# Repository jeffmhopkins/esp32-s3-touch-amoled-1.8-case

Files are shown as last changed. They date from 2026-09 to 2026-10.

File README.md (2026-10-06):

# Deep back plate — ESP32-S3-Touch-AMOLED-1.8

> **Status:** Living · **Last verified:** 2026-10-06

A 3D-printable back cover for the [Waveshare
ESP32-S3-Touch-AMOLED-1.8](https://www.waveshare.com/esp32-s3-touch-amoled-1.8.htm), the little
touchscreen that runs the kids' pet (firmware in
[JBrain2](https://github.com/jeffmhopkins/JBrain2/tree/main/firmware)).
The stock back only fits a tiny battery. This one is a deeper box that holds a real one, screws on
with the original four screw positions, and has grip ribs so small hands don't drop it.

| | |
|---|---|
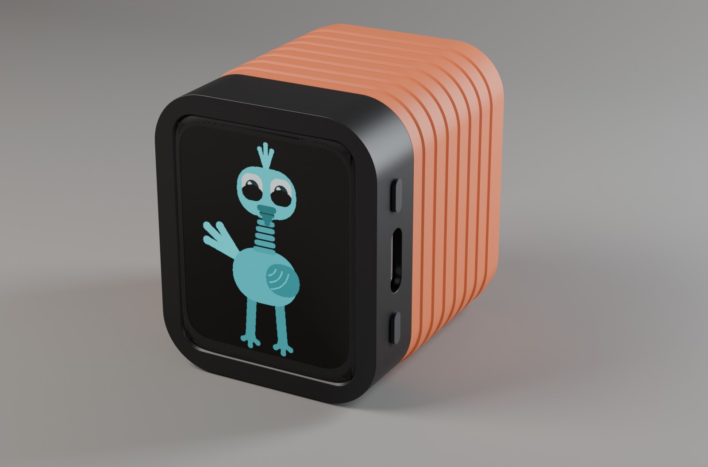
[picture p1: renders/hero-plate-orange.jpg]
The recommended back plate (103035, 1000 mAh) in orange, the pet on its screen
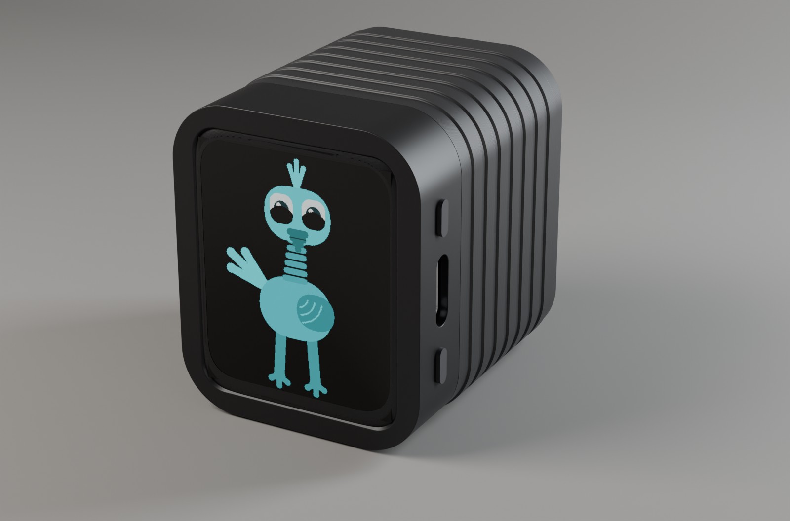
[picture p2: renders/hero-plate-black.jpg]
The same back plate in black
|  |  |

*Rendered from the model, with Waveshare's 3D model of the board and the firmware's own pet on the
glass, in orange and in black. Print it in any colour.*

## Pick a version

| | [**103035, 1000 mAh**](renders/version-103035.png) (recommended) | [802525, 400 mAh](renders/version-802525.png) | [104050, 2400 mAh](renders/version-104050.png) |
|---|---|---|---|
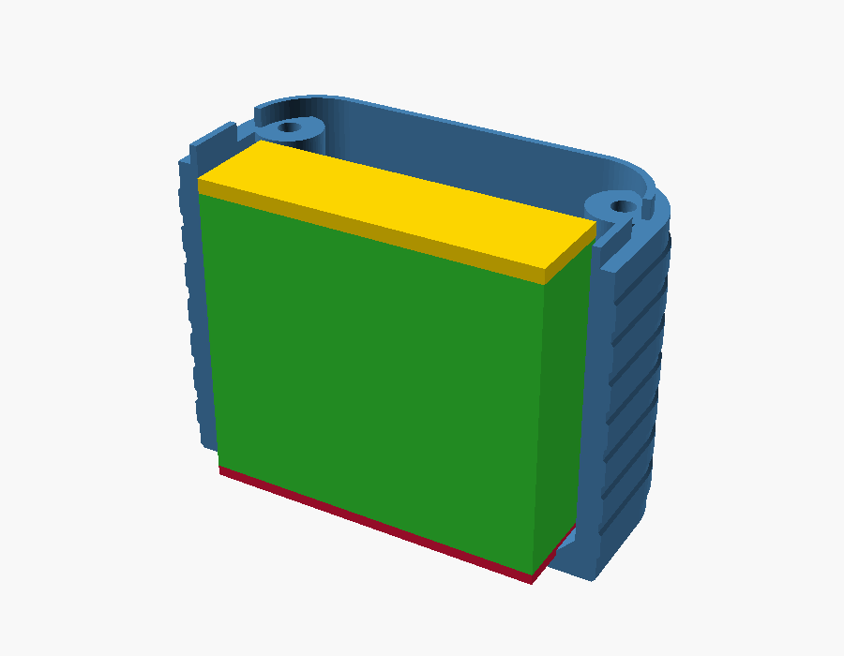
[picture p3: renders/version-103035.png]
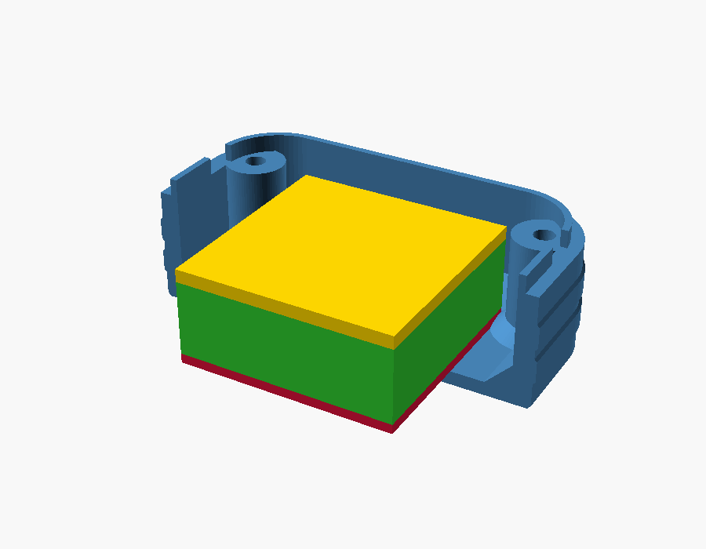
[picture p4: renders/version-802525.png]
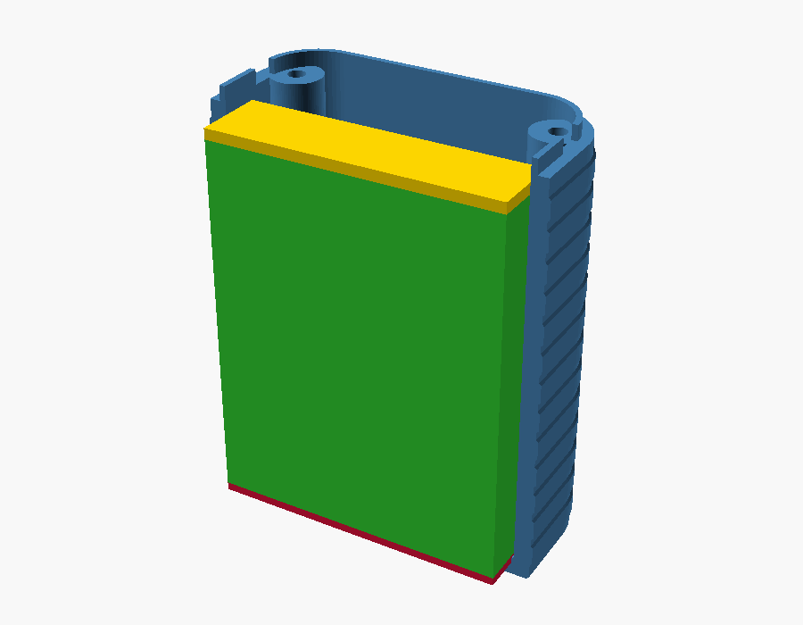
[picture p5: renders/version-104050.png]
| |  |  |  |
| Print | `back_plate_103035_1000mAh_edge.stl` | `back_plate_802525_400mAh_flat.stl` | `back_plate_104050_2400mAh_end.stl` |
| Battery sits | on its edge | flat | on its end |
| Finished unit | 37.6 × 45.2 × 44 mm | 37.6 × 45.2 × 24.7 mm | 37.6 × 45.2 × 67 mm |
| Notes | Roomy fit | Thinnest | Tight fit — measure the cell first |

Green is the battery, red the tape under it, yellow the foam on top. Optional:
`amoled18_hole_plugs.stl`, press-in caps that hide the screw openings — **not for babies, they're
a choking hazard**.

## Or: the desk stand

| | |
|---|---|
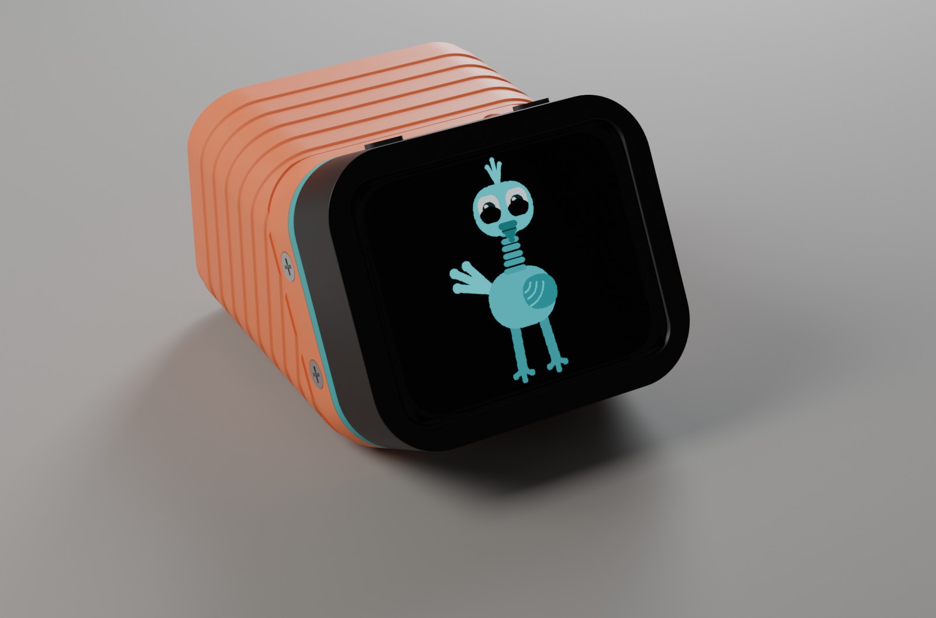
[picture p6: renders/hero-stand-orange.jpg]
The recommended desk stand (103035 box) in orange with a teal head: it lies on its side, the screen leans back 30°, USB-C and buttons along the top, a teal collar between the box and the display
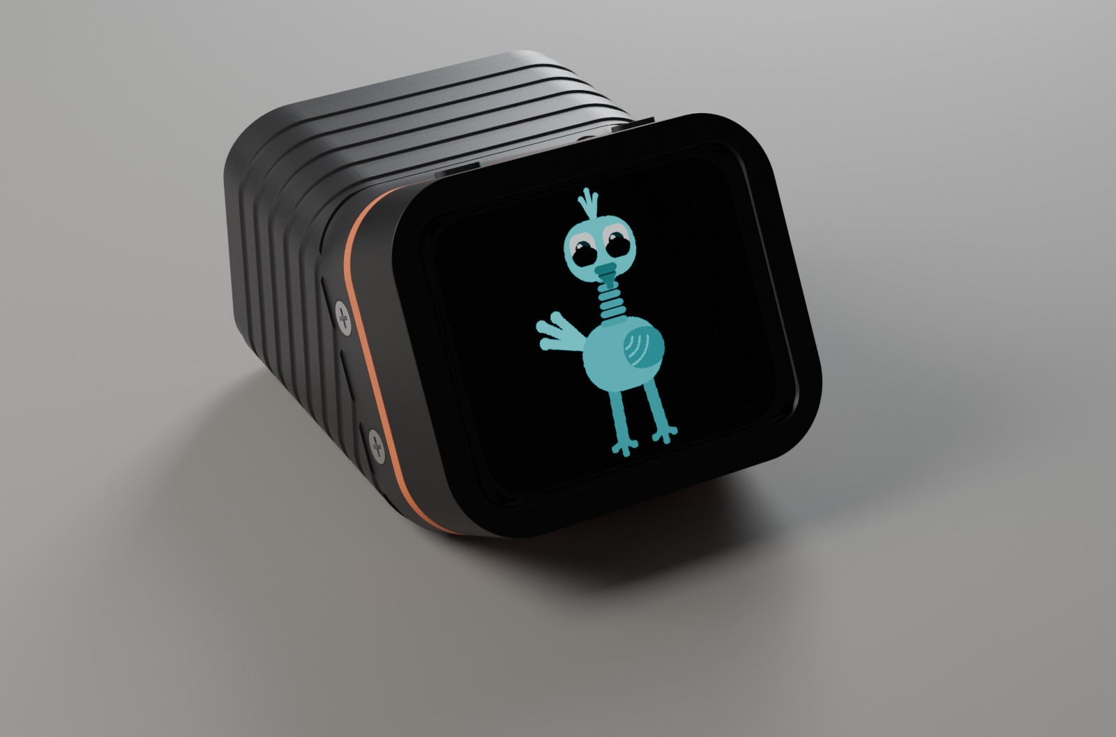
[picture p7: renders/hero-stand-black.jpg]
The same desk stand, a black box with an orange head
|  |  |

A two-part version for a desk. A **head** screws to the display in place of the stock cover,
then sinks into the angled end of a plain **battery box**, held by six flush countersunk
screws round its rim. Above the box the head widens into a 3 mm **collar**, flush with the box
and the front shell, so it shows as a band between them: print the head in a different colour
for each unit to tell them apart. The collar's underside is sloped, so it prints without
supports. The box lies on its long flat side, and the screen faces you,
landscape, leaning back 30° from upright, with the USB-C and buttons along its top edge.
The head is the same for every box, so changing battery only means printing another box.

| | [**103035, 1000 mAh**](renders/stand-section-103035.png) (recommended) | [802525, 400 mAh](renders/stand-section-802525.png) | [104050, 2400 mAh](renders/stand-section-104050.png) |
|---|---|---|---|
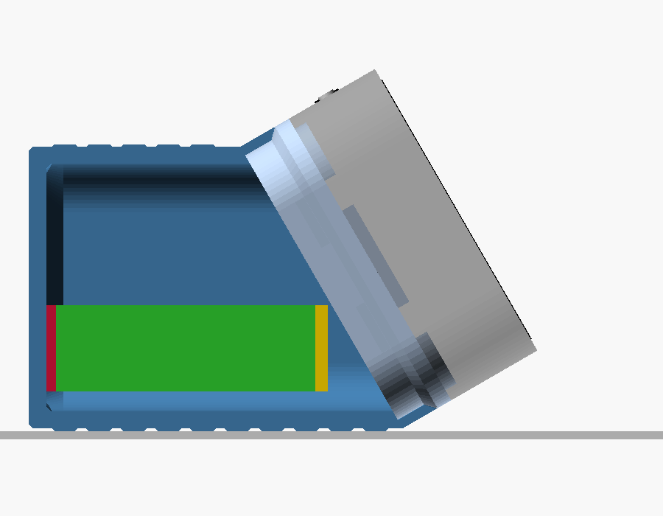
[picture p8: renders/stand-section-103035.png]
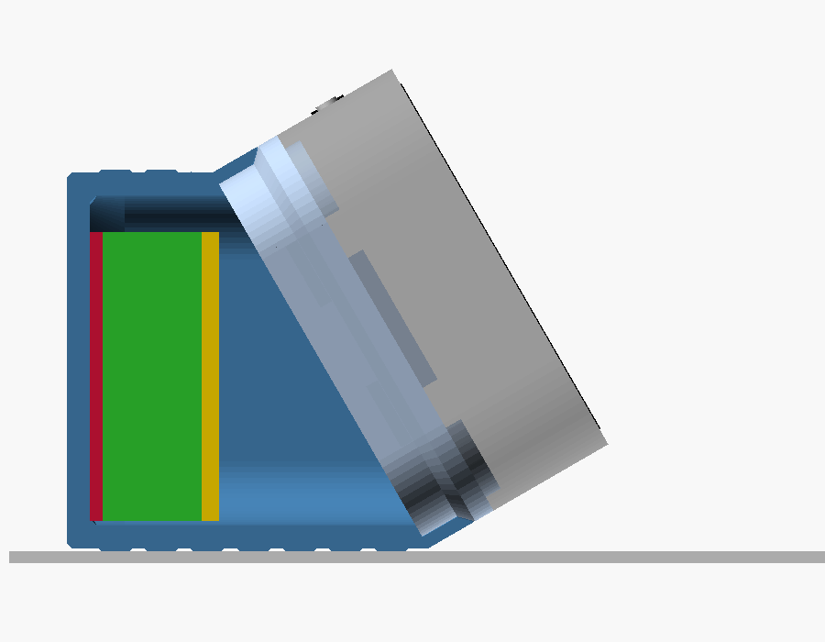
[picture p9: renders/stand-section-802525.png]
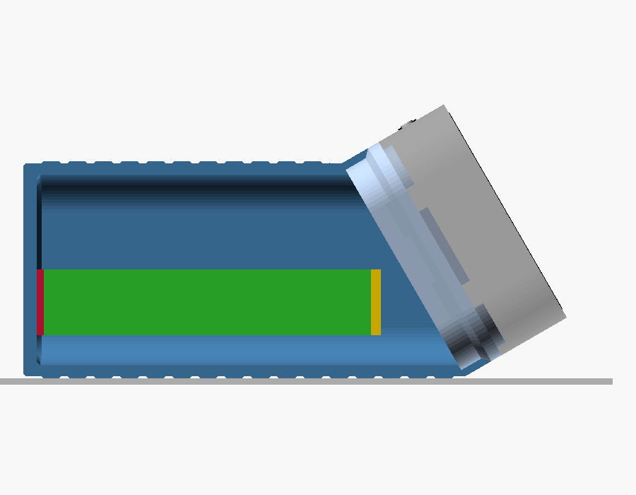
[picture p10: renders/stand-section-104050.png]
| |  |  |  |
| Print | `amoled18_stand_head.stl` + `amoled18_stand_box_103035_edge.stl` | head + `amoled18_stand_box_802525_flat.stl` | head + `amoled18_stand_box_104050_end.stl` |
| Box | 46 × 45 × 34 mm | 34 × 45 × 34 mm | 71 × 45 × 34 mm |
| With the display on | 59 × 45 × 42 mm | 47 × 45 × 42 mm | 83 × 45 × 42 mm |
| Notes | Roomy | Shortest | Tight fit — measure the cell first |

Each is cut open as it sits on the table, you on the right: battery green, tape red, foam yellow.
Sizes are front to back × left to right × height. How to print and assemble it:
[PRINTING.md](PRINTING.md#desk-stand).

If you'd rather not have the collar, `amoled18_stand_head_no_collar.stl` is the same head at
the stock cover's height. It needs boxes without the collar's 45° ramp: export them from the
box presets with `collar_h` set to 0 ([MODEL_ADJUSTMENT.md](MODEL_ADJUSTMENT.md#the-head-presets)).

## The guides

| I want to… | Read |
|---|---|
| Print it and put it together | [**PRINTING.md**](PRINTING.md) |
| Change it: another battery, a better fit, different grip | [**MODEL_ADJUSTMENT.md**](MODEL_ADJUSTMENT.md) |
| Fix something that came out wrong | [**TROUBLESHOOTING.md**](TROUBLESHOOTING.md) |
| Understand how it's built and where every number came from | [DESIGN.md](DESIGN.md) |

## Safety

These go to small children. Keep the hole plugs away from babies (glue them in or leave them
off), never squeeze a lithium pouch cell, don't install one that's puffed or damaged, check the
battery plug's polarity before connecting it, and don't leave it charging unattended.

## What's in this repo

| File | What it is |
|---|---|
| `back_plate_*.stl` | Ready-to-print plates, one per version |
| `amoled18_hole_plugs.stl` | Six press-fit plugs |
| `amoled18_stand_head.stl`, `amoled18_stand_box_*.stl` | The desk stand: one head (with its collar), a box per battery |
| `amoled18_stand_head_no_collar.stl` | The same head without the collar (for boxes made with `collar_h` 0) |
| `amoled18_back_plate.scad` | The adjustable model ([MODEL_ADJUSTMENT.md](MODEL_ADJUSTMENT.md)) |
| `amoled18_back_plate.json` | The versions and the desk stand's parts as OpenSCAD presets |
| `renders/` | Every image in these guides, and `make_renders.sh` to regenerate them |
| `photos/` | The real unit |
| `.github/workflows/release.yml` | Cuts a release with every STL attached: Actions tab → Release → Run workflow |
| `reference/` | Archived Waveshare drawings, 3D model, schematic and web pages ([reference/README.md](reference/README.md)) |
| `LICENSE` | CC BY-SA 4.0, below |

## License

The design (the model, STLs, renders, guides and photos) is licensed under
[CC BY-SA 4.0](https://creativecommons.org/licenses/by-sa/4.0/): print it, share it, sell prints,
or remix it, as long as you credit this repo and share remixes under the same license. The
files in `reference/` are Waveshare's, kept unmodified for reference, and are not covered.

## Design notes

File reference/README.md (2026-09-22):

# Reference files

> **Status:** Living · **Last verified:** 2026-09-22

Waveshare's published files for the ESP32-S3-Touch-AMOLED-1.8, kept here so the back plate's
defaults can be checked without depending on their site staying up. Every file here is an
unmodified copy of Waveshare's original; the table says where each one came from.

| File | What it is | Used for |
|---|---|---|
| `waveshare-dimensions.webp` | Official dimension drawing ([source](https://docs.waveshare.com/ESP32-S3-Touch-AMOLED-1.8)) | Case outline 37.6 × 45.2 × 15.0 mm, corner radius, back label window 27.6 × 27.6 R1.8 |
| `waveshare-3d-model.zip` | STEP model of the board and display, without the case shells ([source](https://files.waveshare.com/wiki/ESP32-S3-Touch-AMOLED-1.8/ESP32-S3-Touch-AMOLED-1.8-3D.zip)) | PCB 33.0 × 40.6 mm and its four mounting holes, 24 × 36 mm apart |
| `waveshare-schematic.pdf` | Board schematic ([source](https://files.waveshare.com/wiki/ESP32-S3-Touch-AMOLED-1.8/ESP32-S3-Touch-AMOLED-1.8.pdf)) | Battery connector and charging circuit |
| `pages/` | Saved copies of the web pages the numbers came from (see below) | Keeping the sources if Waveshare's site changes |
| `measure.py` | Re-derives the numbers above from these files | Checking or updating the `.scad` defaults |

## Saved web pages

Saved 2026-09-22. Open them in a browser; they read fine offline, though images other than
the dimension drawing aren't included.

| File | Page | How it was saved |
|---|---|---|
| `pages/docs-main.html` | [Waveshare docs: overview](https://docs.waveshare.com/ESP32-S3-Touch-AMOLED-1.8), with the dimension drawing and the MX1.25 battery connector | Direct download |
| `pages/docs-resources.html` | [Waveshare docs: resources](https://docs.waveshare.com/ESP32-S3-Touch-AMOLED-1.8/Resources-And-Documents), the download links above | Direct download |
| `pages/wiki.html` | [Waveshare wiki](https://www.waveshare.com/wiki/ESP32-S3-Touch-AMOLED-1.8): "recommended battery specification is 3.85\*24\*28 400mAh" | Wayback Machine snapshot from 2026-07-23 (the live site blocks scripted downloads) |
| `pages/product.html` | [Product page](https://www.waveshare.com/esp32-s3-touch-amoled-1.8.htm): "to fit inside the case, a battery size of 3.85 × 24 × 28 mm is recommended" | Wayback Machine snapshot from 2026-09-14 |

## Using the files

The STEP file opens in any CAD program (FreeCAD, Fusion 360, Onshape) — handy for checking
clearances between the battery pocket and the parts on the back of the board.

`measure.py` output, for comparison:

```
PCB: 33.01 x 40.62 x 1.20 mm
  hole centre: (-12.05, -18.05) mm from board centre
  hole centre: (-12.09, +18.10) mm from board centre
  hole centre: (+12.06, -18.05) mm from board centre
  hole centre: (+12.01, +18.00) mm from board centre
Case corner radius: 8.8 mm (fit error 0.23 px²)
```

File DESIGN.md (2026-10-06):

# Design notes

> **Status:** Living · **Last verified:** 2026-10-06

How the plate is built, why, and where every number came from. You don't need this to print or
adjust it. Back to the [README](README.md).

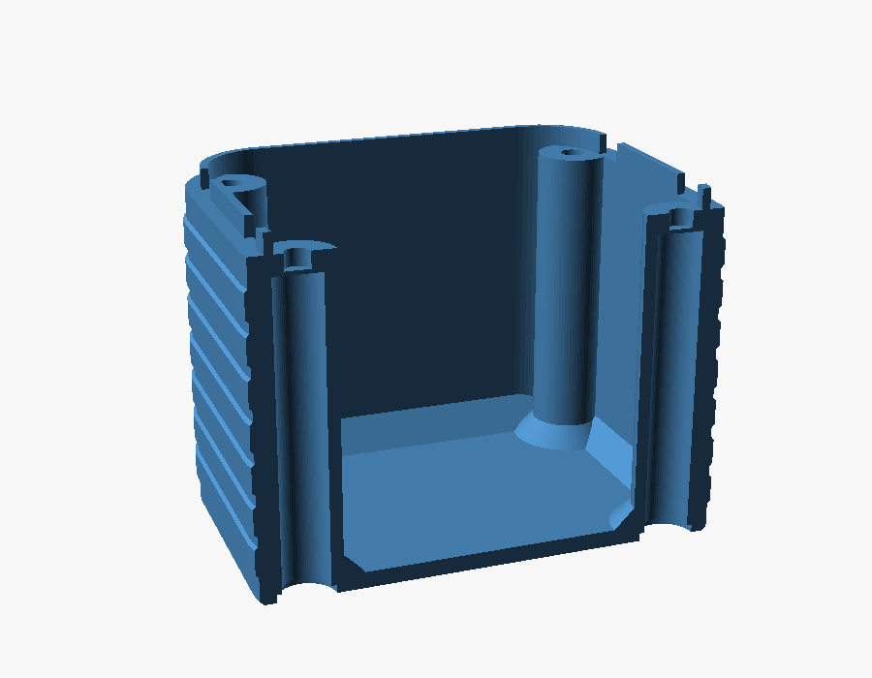
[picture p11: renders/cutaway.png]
Cut through two screw towers


## Battery cavity

The plate is a box with straight walls. The whole inside is open apart from four screw towers,
and its depth follows the battery. The cell sits on tape with foam on top, and the cavity is
deliberately not shaped to the cell: gaps are packed with foam. All ports, buttons and the mic
are in the front shell, so the plate has no other openings.

- **Orientation.** The screws pass through 24 mm apart across the case, so a wide cell can't lie
  flat past them. On its **edge** a cell is only its thickness wide there; on its **end** its
  length becomes the plate's depth, so any length fits.
- **Wire room.** A pouch cell's wires leave one end. `lead_end` (2 mm) keeps that free; the
  default still has 1.85 mm spare at each end beyond it. A 40 mm cell such as an 852540 doesn't
  fit flat or on its edge once its wires have room.
- **Clearances.** The console warns `TIGHT` when anything comes within 0.5 mm of the cell and
  refuses to export under 0.2 mm, because real cells run up to half a millimetre over.
- **Bracing.** A 45° chamfer where the walls meet the floor (`wall_chamfer`, 3 mm) and a 45°
  flare where each tower meets it (`tower_flare`, 2 mm). Both shrink near the cell to stay
  0.5 mm off its bottom edge, so they never lift it.
- **The board's `BAT` connector** stands 3.5 mm off the back of the board, on one long side about
  halfway along. The flat 802525 sits under it, so that version leaves 2 mm extra above the cell.
- **The rim** is the top of the wall itself (0.8 mm), so it stands squarely on the wall with
  nothing overhanging. Its opening is the cavity. It has a 4 mm slot 8.5 mm either side of the
  middle of each short side (`mic_slots`), behind the U-shaped speaker/mic notch in the front
  shell's edge, so the rim doesn't close that notch off. There are four so it clears whichever
  way round the part goes on; the shell hides the ones it doesn't need.

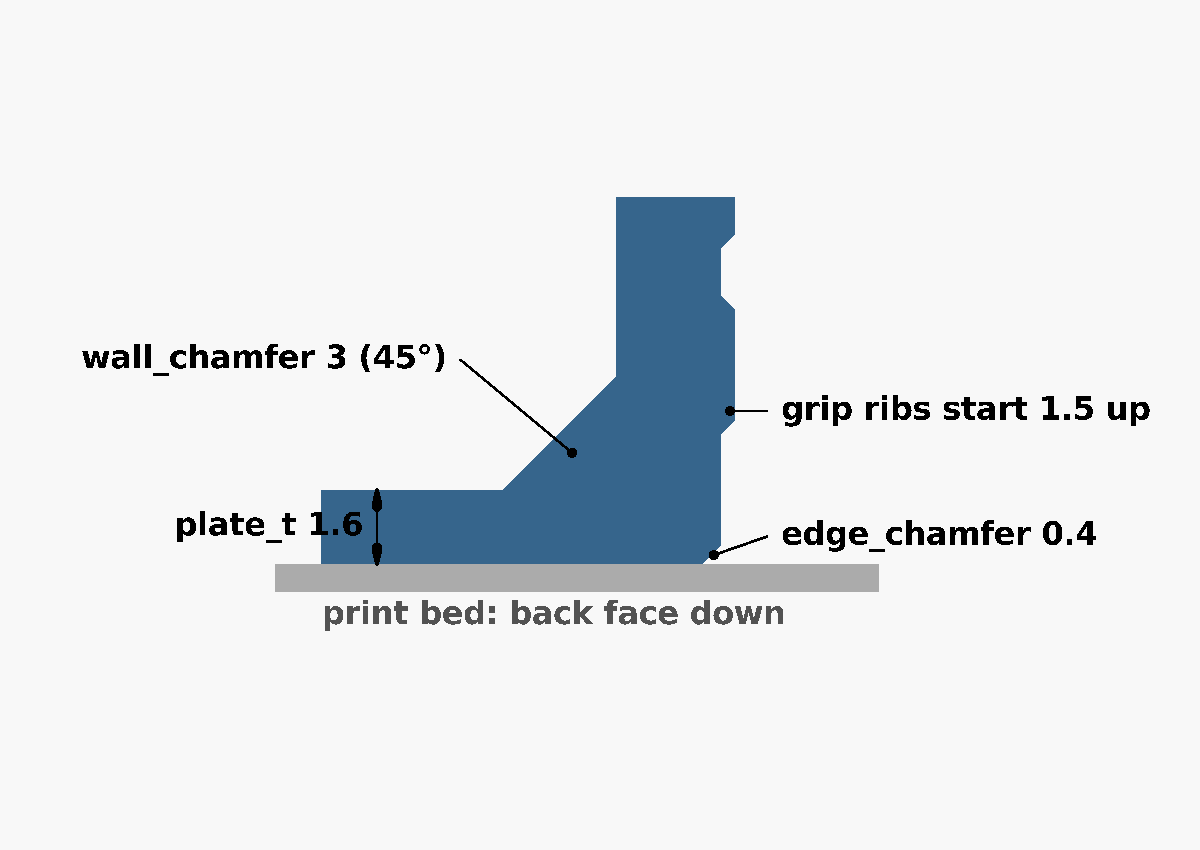
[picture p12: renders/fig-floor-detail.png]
Bottom of the wall: floor, chamfer, bed edge


## Screws

The screws thread into brass hex standoffs soldered to the **board**, not the case. They stand up
from the board and end exactly level with the front shell's edge. On the stock cover a post
around each screw presses its standoff, so tightening clamps the board. This plate does the same
with four hollow towers:

- The bore (Ø4.6) takes the screw head and hex key up to the **seat**, 2 mm of plastic at the top
  (`head_seat`). The screw only passes through the seat into the standoff, so short screws work
  at any plate height.
- The tower top is flat and full width (Ø7) and stops at the seam, level with the front shell's
  edge, where it presses squarely on the standoff (`tower_drop` = 2, the rim's height). The rim
  then goes its full 2 mm into the shell. If the top ever needs to stand clear of parts near a
  standoff, `nut_pad_h` raises a Ø4.5 pad around it instead.
- A thin skin (`bridge_skin`, 0.4 mm — two layers) closes each bore so the printer can bridge it;
  it's cleared at assembly.

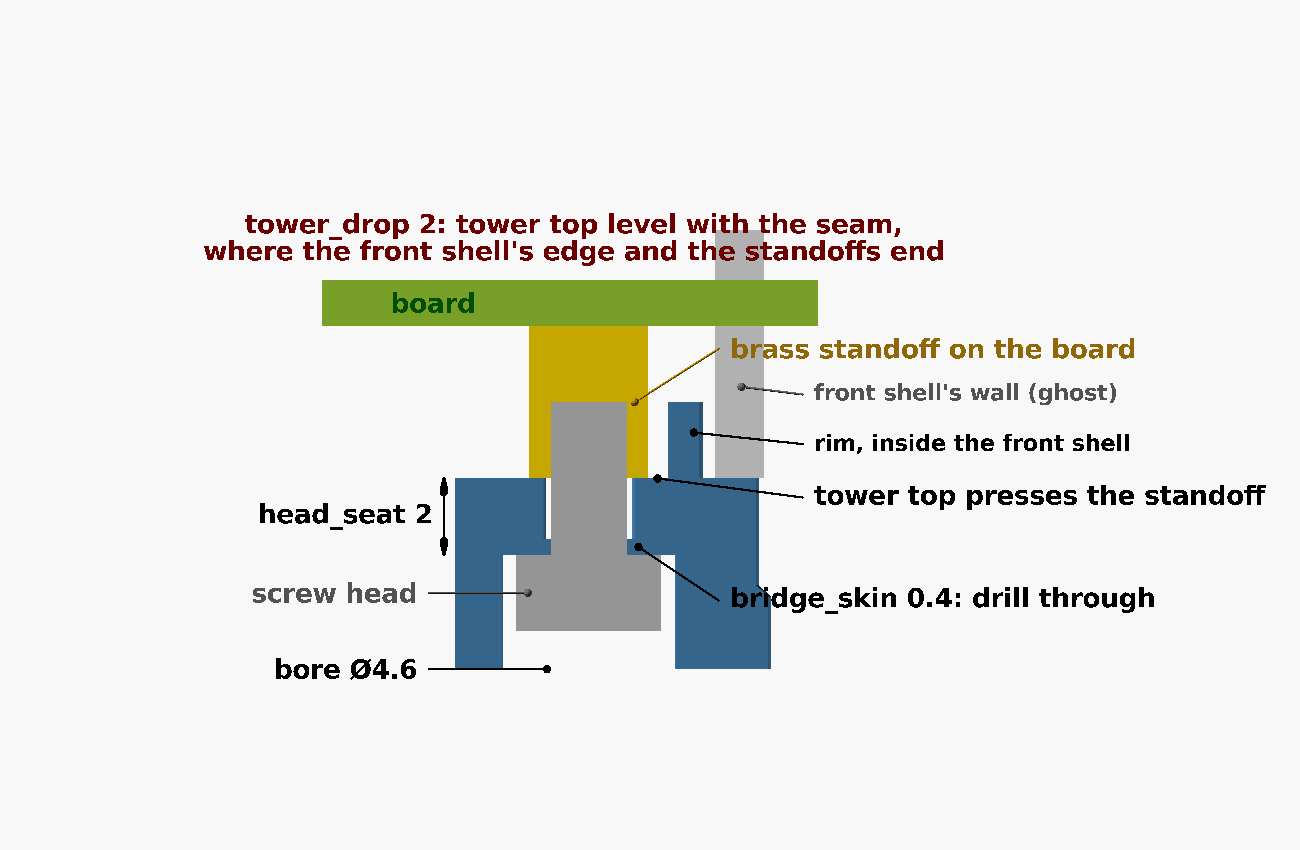
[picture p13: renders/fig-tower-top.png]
Top of a screw tower, with the screw, the board's standoff and the board


| The standoffs end level with the front shell's edge | The four standoffs on the board |
|---|---|
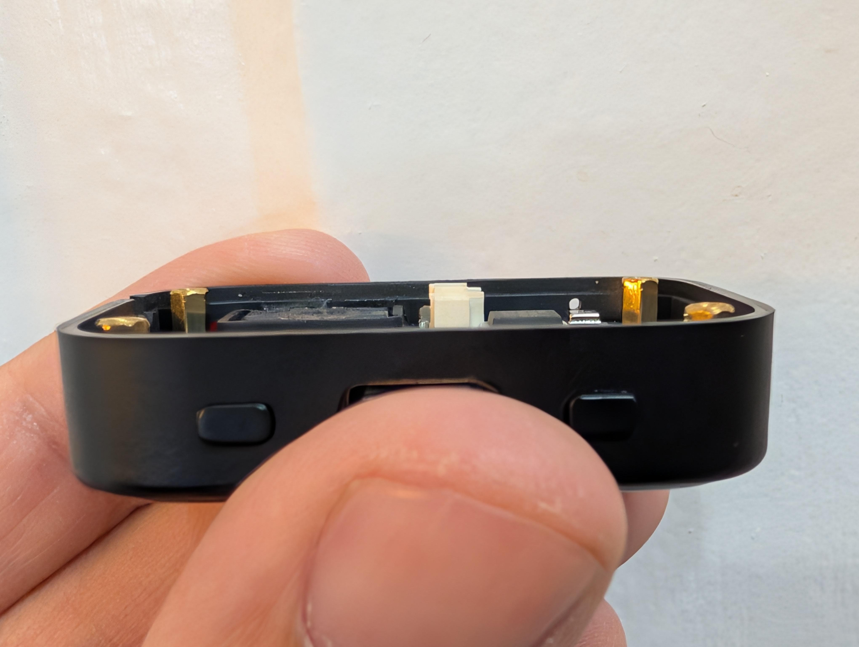
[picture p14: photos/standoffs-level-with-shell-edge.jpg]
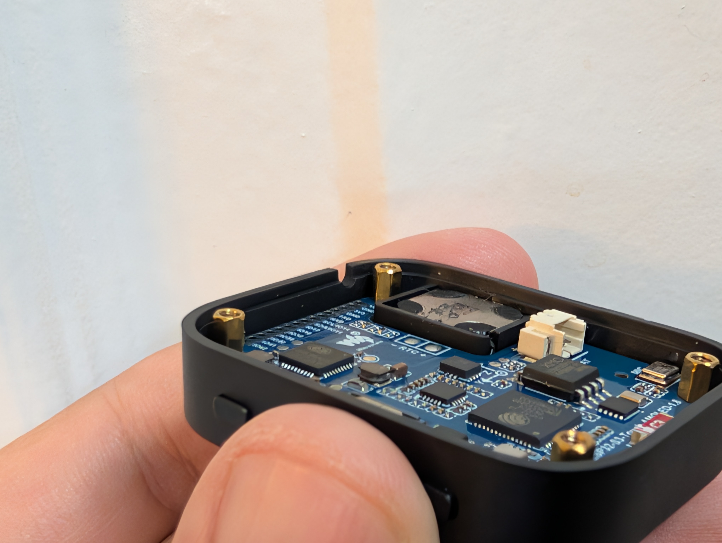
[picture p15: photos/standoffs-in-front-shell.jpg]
|  |  |

**Screw length.** The screw passes the 2 mm seat and goes into the standoff; M2 × 4 gives 2 mm of
thread in it, M2 × 5 gives 3. Push a stock screw through the stock cover to see how far it goes
into its standoff, and don't go much past that: the standoff's thread may not run its full
length. On the desk stand's head the seat is 1.4 mm (the head is too thin for a socket head
under a 2 mm seat), so its M2 × 4 go 2.6 mm in.

## Hole plugs

A shallow recess (Ø5.6 × 0.8) at each tower opening, and plugs with a thin cap and a ribbed
shank: six ribs that crush slightly going in, for a press fit with no glue. A small gap around
each cap lets a knife tip pry it out. They're a choking hazard for babies.

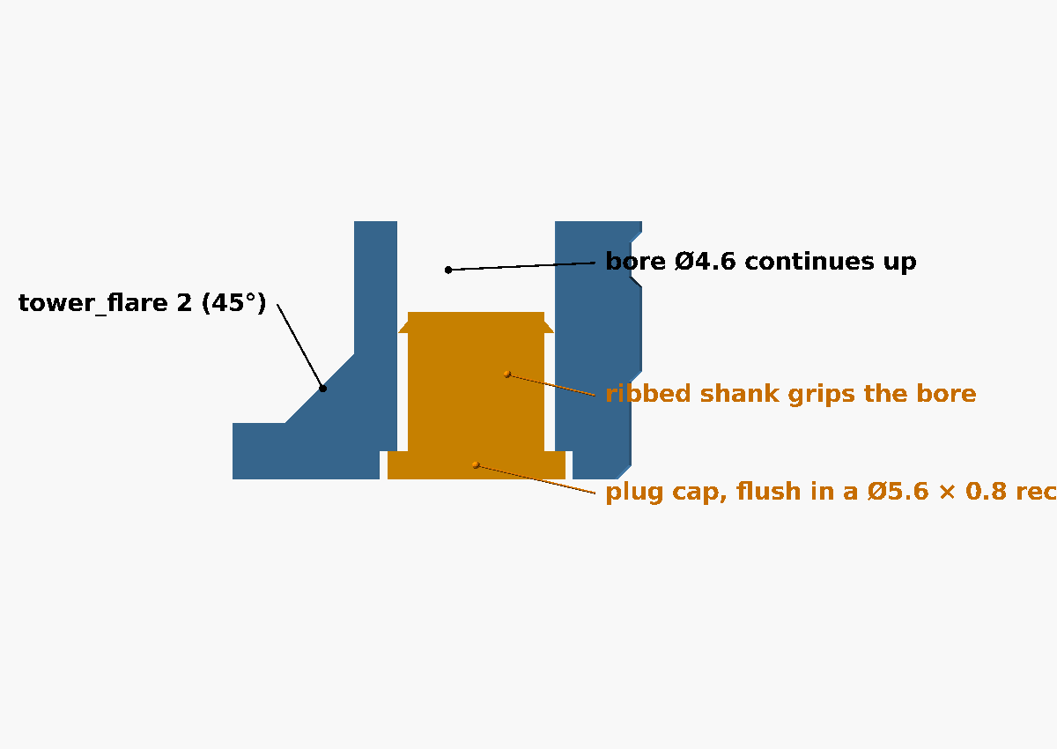
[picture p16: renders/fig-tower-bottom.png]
A fitted plug in section


## Grip

Horizontal ribs right round the outside, corners included: bands 3 mm tall, 0.3 mm proud by
default (`grip_depth`, 0–0.5), with 45° slopes top and bottom so they print without supports.
They stop 1.5 mm short of the bed edge and the seam.

## The tall 104050 version

A 104050 (10 × 40 × 50 mm, sold as 2400 mAh; expect about 2000) standing on its 10 × 40 face,
wires at the top, about 67 mm tall overall. Its 40 mm width sits in a 40.7 mm opening — 0.35 mm
per end, hence "measure first"; set `lip_wall` to 0.6 for 41.1 mm if it's over. The common
listing ships a JST PH 2.0 plug that needs swapping for 1.25 mm. The screws are the same M2 × 4;
the hex driver needs a 60 mm shaft.

## The desk stand

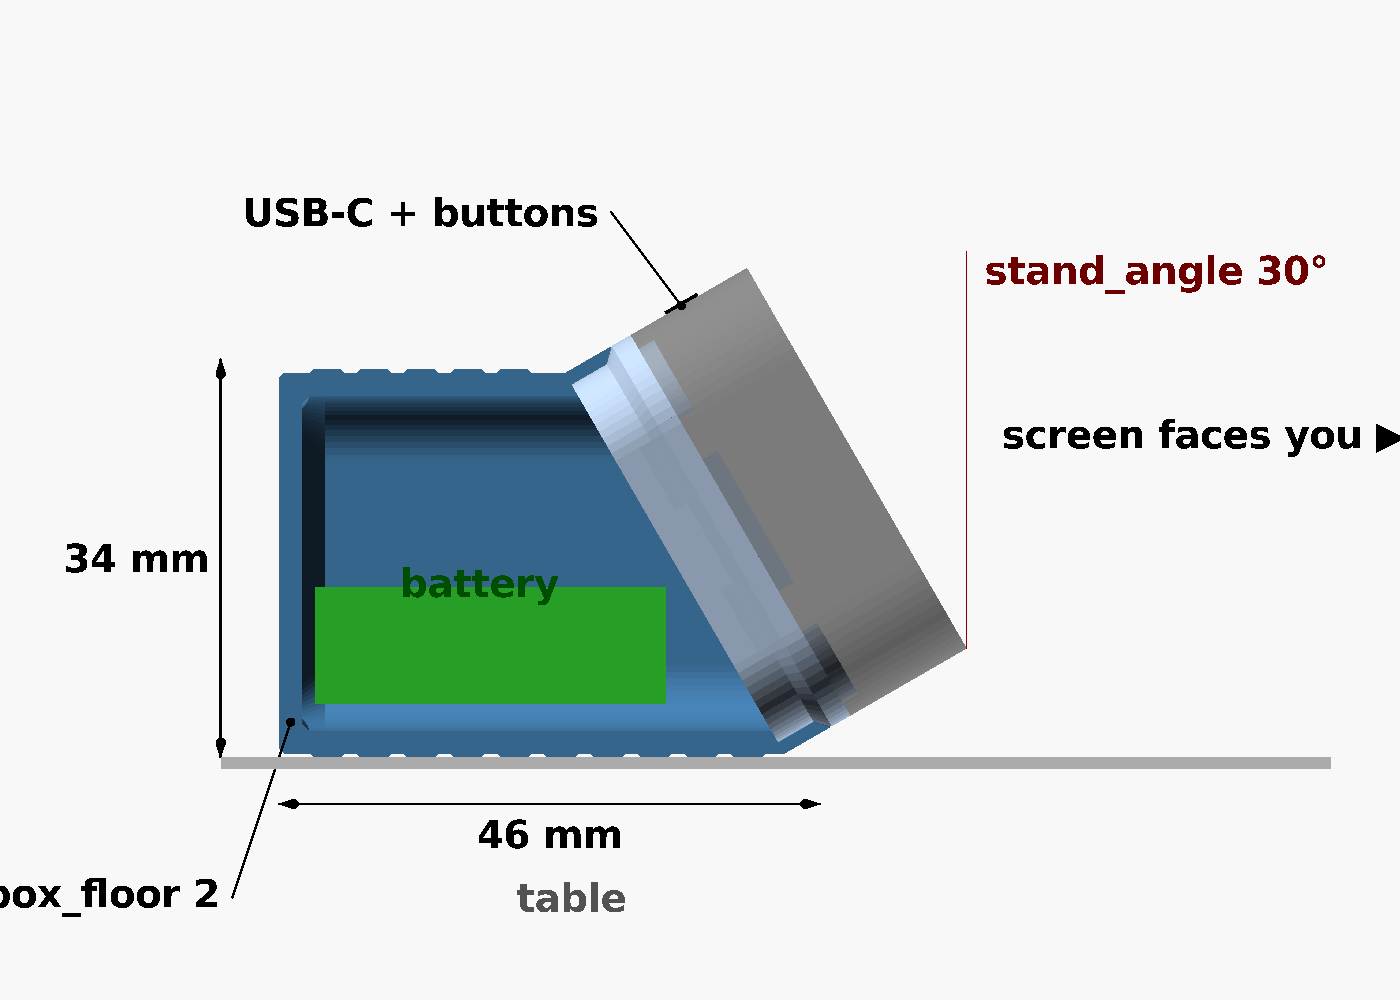
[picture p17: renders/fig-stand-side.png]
The desk stand from the side


Two parts, so the box stays a plain box and the part that meets the display stays the stock
cover's shape. The head that ships adds a collar and a few fit changes to what's described
below (the model's defaults, which the boxes are built from); see
[The collar head](#the-collar-head) at the end of this section.

- **The head** is the plate at stock depth (5.5 mm) with no battery room: same rim, same four
  towers, so it fits the front shell exactly as the stock cover does. It is smaller than the case
  by the box's rim wall, with corners that follow the case's: the box's opening is the case outline
  offset in by the band's width, so the band is the same 1.1 mm all the way round, corners
  included. (Tighter head corners pinched the band to 0.3 mm at each corner, too thin to
  print.) That leaves 0.83 mm of wall outside each screw bore in the head, with the head
  presets' slightly tighter bore (`head_clear` 0.4). It adds a solid block for each lock screw
  inside its short ends (left and right in
  use), and a slot through the floor just in front of the board's `BAT` socket, whose mouth faces
  the slot (from Waveshare's 3D model). The socket is on the side away from the USB-C, which fixes
  which way round the head goes. Its back edge has no chamfer, so all of it bears on the ledge,
  and its tower flares don't change with the battery, so one head fits every box.
- **The box** is a straight-walled prism, printed standing on its floor. Its open end is cut at
  `stand_angle`, and the head sinks into it: its back rests on a ledge `stand_ledge` wide inside,
  and round it the box's wall carries on `pocket_wall` thick to the seam, where the front shell
  sits on it. The outside of that band is the case outline, so box and front shell are flush;
  the head's rim stands above the seam into the front shell as usual. Below the ledge the box is
  open under the head, so the head's back is its lid. Where its walls meet the floor there's a
  45° chamfer, kept under the tape beside the cell as on the plate.
- **How it sits.** In use the box lies on its long flat wall, with the cut end facing you, so the
  screen leans back `stand_angle` from upright. The display goes in with its USB-C edge (the
  head's +x, where the two buttons are too) to the box's short wall, which puts it along the top.
  Nothing of the box stands past the seam, so the USB-C plug and the buttons are clear. Lying on
  a side 45 mm wide and as long as the box, it's low and steady.
- **Box size.** The cell lies on that long flat wall, as far along it as its corners allow 0.5 mm
  from the rounded corners. The box is then made just long enough that the head clears the top of
  the cell (in the print frame) plus tape, foam, wires and `extra_clearance`, but its short wall
  is never shorter than `stand_front_min`. The box is modelled in its print frame; `part = stand`
  shows it lying as it's used (`stand_pose()` in the `.scad`).
- **Printing.** Standing on its floor, the box's walls are vertical and its cut end slopes at
  `stand_angle`, so it prints with no supports; the band's walls lean at that angle too, the
  same as the front shell's. The band is 1.1 mm at the sides and about 1.3 mm along the long and
  short walls.
- **Screws.** Four M2 × 4 hold the display to the head, as on the plate, though here the seat is
  1.4 mm and the holes 2.1 mm deep so a socket head fits inside the thin head. Six M2 × 8
  countersunk lock screws hold the head in the box: two on each side, `lock_spread` (14 mm) apart,
  and one each in the top and bottom, diagonally opposite so they clear the battery slot and the
  head still fits either way round. Each goes through the band round the box's angled end into a
  lock block in the head, cutting its own thread about 5.6 mm deep. An M2 countersunk head needs
  only a 0.8 mm 90° seat, so the heads sit flush in the 1.1 mm band. The holes are 1.45 mm up from
  the ledge, which keeps each seat under the seam with the front shell; its lower edge dips into
  the solid wall below the ledge.
- **Pads and notches.** The band alone is 1.1 mm, thin for a screw to clamp on, so at each screw
  the box has a pad on the band's inside, 6 mm wide, reaching `lock_pad` (1.0 mm) in — no further
  than the ledge, so it stands on solid wall — and the head has a matching notch in its edge. The
  wall under each screw head is 2.25 mm. The notch's roof, and the pad's top, slope at 45°, so the
  head's rim above each notch is held up by solid plastic instead of printing as a bridge. The
  pads also key the head into the box before it's screwed.

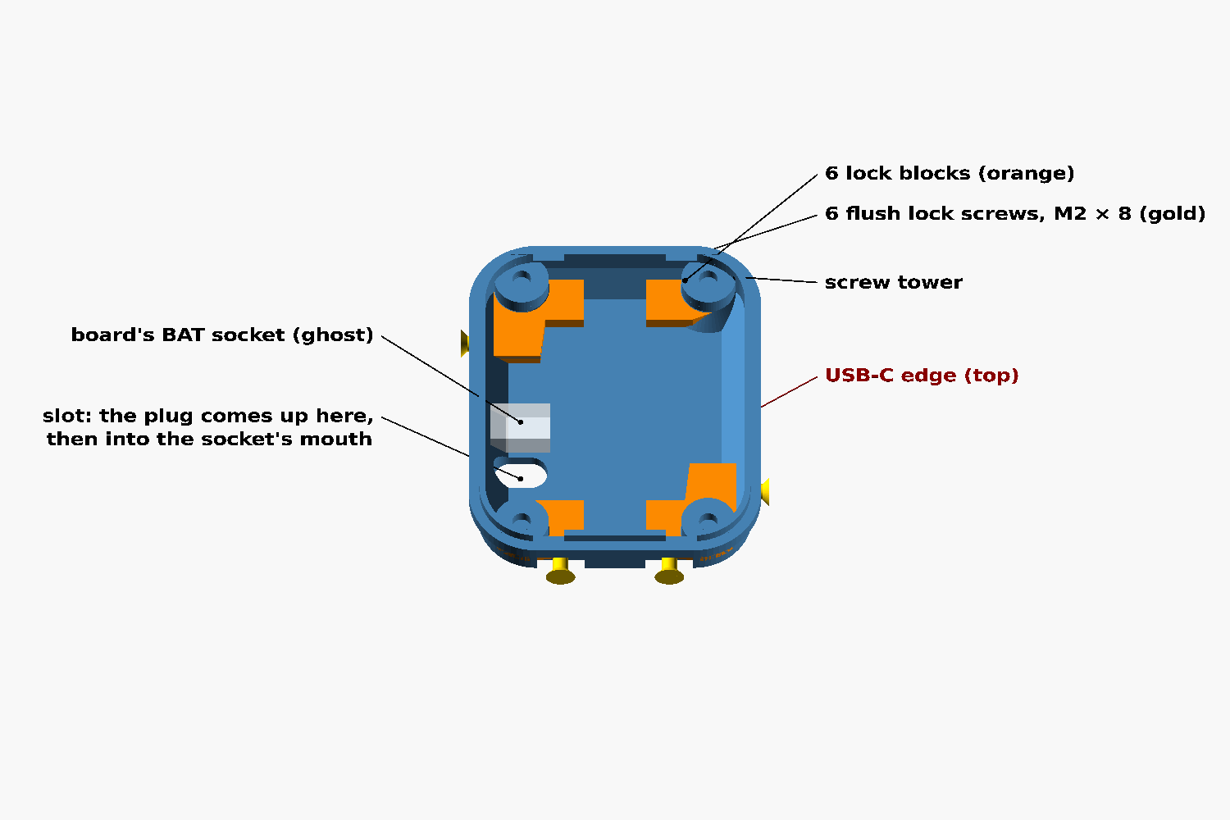
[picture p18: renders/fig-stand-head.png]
The head from inside, with the BAT socket ghosted


### The collar head

The head that ships (`amoled18_stand_head.stl`, preset **Desk stand: head (fits every box)**)
is the head above with these changes; `amoled18_stand_head_no_collar.stl` (preset **Desk
stand: head, no collar**) has all of them but the collar. Each one came from fitting a stand
on a second unit, where the stock head was loose in the box and the front shell sat above it.

- **A 3 mm collar** (`collar_h`). Above the box's band the head widens to the case outline,
  so the box, collar and front shell are flush. The part in the box (`pocket_h`) is unchanged.
  The collar's underside slopes up at 45° from the head's side (`collar_chamfer`), so it prints
  without a sagging overhang, and the box's band rises in a matching 45° ramp that the
  collar nests on, 0.1 mm clear. The boxes therefore carry `collar_h` too: a box made with it
  has the ramp. The collar head also fits a box without the ramp, leaving a small V-groove
  between them; the no-collar head needs a box without the ramp.
- **Tower tops 0.5 mm below the seam** (`tower_drop` = `lip_h` + 0.5), so standoffs that reach
  past the shell's edge can't hold it up. The screw seat stays 2 mm thanks to the collar, and
  the screws become M2 × 5.
- **Lock blocks stay in the box** (they stop at `pocket_h`), 3 mm below the seam, and join
  their nearest tower (`lock_block_join`) so there's no narrow V between them.
- **A 1.5 mm rim** (`lip_h`; `stock_clear` drops with it so the part in the box stays 3.5 mm).
- **0.05 mm gaps** to the box and inside the shell (`pocket_clear`, `lip_slop`), with the
  lock-pad notches 0.1 mm deeper (`lock_pad`, `stand_ledge` 1.1) to match.

## Where the numbers come from

Sources: Waveshare's [dimension drawing](https://docs.waveshare.com/ESP32-S3-Touch-AMOLED-1.8) and
[3D
model](https://files.waveshare.com/wiki/ESP32-S3-Touch-AMOLED-1.8/ESP32-S3-Touch-AMOLED-1.8-3D.zip)
([resources page](https://docs.waveshare.com/ESP32-S3-Touch-AMOLED-1.8/Resources-And-Documents)),
and the photos in `photos/`. Copies are kept in [`reference/`](reference/README.md), with
`reference/measure.py` to re-derive them. The 3D model has the board and display but not the case.

| Default | Value | Source | Confidence |
|---|---|---|---|
| `plate_x` × `plate_y` | 37.6 × 45.2 | Case outline, dimension drawing | High (official) |
| `screw_dx`, `screw_dy` | 12.0, 18.0 (24 × 36 apart) | PCB mounting holes in the 3D model; drawing and photos agree within ~0.7 mm | High |
| `plate_r` | 8.7 | Circle fitted to the drawing's corners | Good, ±0.5 |
| `lip_outer_x` × `lip_outer_y`, `lip_outer_r` | 35.0 × 42.6, 7.4 | Outline minus a ~1.3 mm front-shell wall, from the photos (the board is 33.0 × 40.6) | Estimate: measure |
| `lip_h` | 2.0 | Not visible in any source | Guess: measure |
| `stock_clear` | 3.9 | Stock cover shows 3.5 mm in the side view; derived with the rim height | Estimate |
| `tower_drop` | 2.0 (= `lip_h`) | The board's standoffs end level with the front shell's edge ([photos](#screws)); 0 left a 2 mm gap at the seam on the first print | Measured |
| `lip_wall` | 0.8 | Chosen: the rim's inside is the cavity; 0.8 leaves a 40.7 mm opening | Design choice |
| `screw_size` | M2 | Heads ~3.8 mm across in the drawing (stock ones are Phillips) | Likely |
| Tower bore | Ø4.6 | ISO 4762 M2 head (Ø3.8) + `head_clear` 0.6 + `hole_slop` 0.2 (Ø4.4 in the desk-stand heads, `head_clear` 0.4) | Standard |

For reference: the stock unit is 15.0 mm thick; Waveshare's largest recommended cell for the
stock case is 3.85 × 24 × 28 mm; the stock back label window is 27.6 × 27.6 mm, R1.8.

The desk-stand head presets (`amoled18_stand_head.stl` and the no-collar head) go on from these
defaults: a 1.5 mm rim and tower tops 0.5 mm below the seam, from fitting a second unit whose
shell sat proud of the box on the defaults ([The collar head](#the-collar-head)).

## Regenerating the images

Every image in these guides is rendered from the model: `renders/make_renders.sh` rebuilds them
all (OpenSCAD 2021+; on a headless machine it uses `xvfb-run`). The figure sources are in
`renders/src/`; the labelled ones draw their dimension lines and text in OpenSCAD itself
(`renders/src/annot.scad`), so a change to the model only needs a re-run.

The photoreal shots on the README, `renders/hero-<plate|stand>-<orange|black>.jpg`, come from
`renders/photoreal/make_photoreal.sh` instead: Blender (Cycles, as the `bpy` module) renders
the printed parts exported from the model, Waveshare's STEP of the board and panel (the copy in
`reference/`, checksummed), and a pet frame drawn by the JBrain2 firmware's `face.c` (saved in
`renders/photoreal/screens/`; set `FIRMWARE` to a firmware checkout to redraw it). The STEP has
no case, so the black front shell in those shots is drawn from the case outline and the
[photos](#screws): the board hangs on standoffs that end at the seam (taken as 4 mm), which puts
the glass just under the shell's face. It takes about 25 minutes on four cores and needs `python3.11`; re-run it only
when a change shows from outside.

## Photos of the real unit

| Stock cover, inside | Assembled back | Board in the front shell |
|---|---|---|
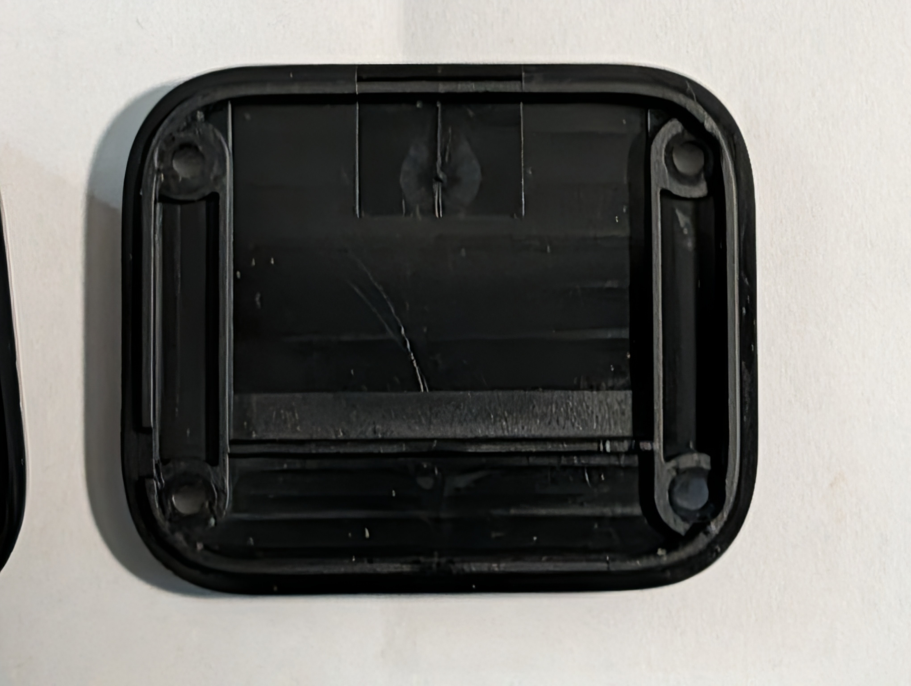
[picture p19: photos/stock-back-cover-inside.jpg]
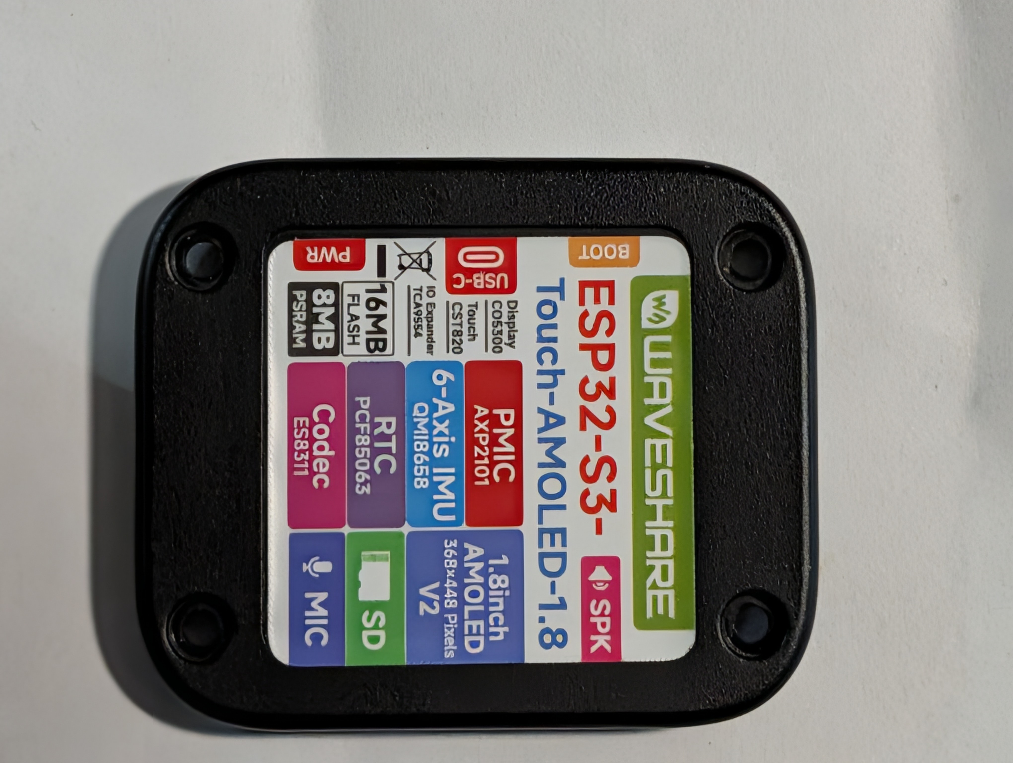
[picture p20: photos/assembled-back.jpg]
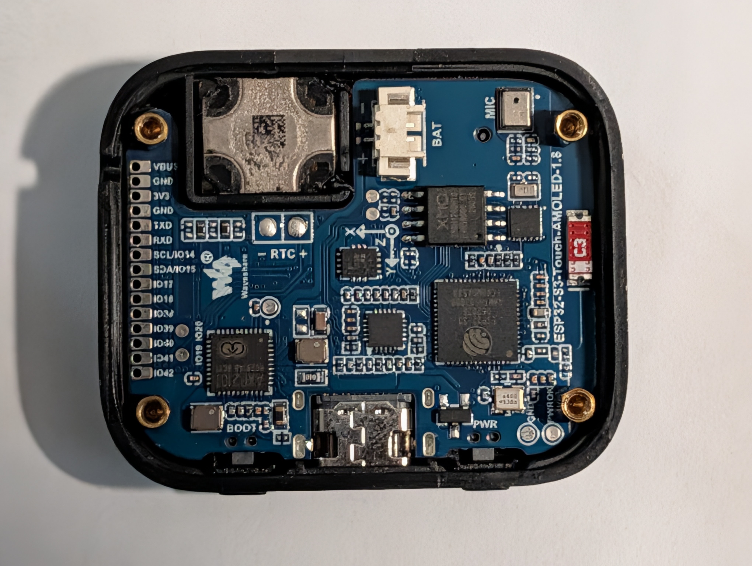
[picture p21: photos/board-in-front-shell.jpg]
|  |  |  |

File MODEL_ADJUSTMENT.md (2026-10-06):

# Adjusting the model

> **Status:** Living · **Last verified:** 2026-10-06

How to change the plate: another battery, a better fit to the case, a different grip. You never
edit code — every number is a labelled field in a form (the one exception is noted under the desk
stand). Back to the [README](README.md).

## Opening it (first time)

1. Install [OpenSCAD](https://openscad.org/downloads.html) (free, Windows/Mac/Linux).
2. Download `amoled18_back_plate.scad` **and** `amoled18_back_plate.json` into the same folder
   (on GitHub: click the file, then the download icon). The `.json` holds the ready-made versions.
3. Open the `.scad`. Turn on the form: **Window → Customizer** (on some versions untick **View →
   Hide customizer**). Press **F5** to see the part; drag to spin, scroll to zoom.
4. **Start from a version**: the drop-down at the top of the Customizer has all three, and
   the desk stand's head and boxes. Then
   change fields — the groups are numbered, and each field has a plain-English label.
5. **Read the console** at the bottom (**Window → Console** if hidden) after each **F5**:
   - `All checks passed.` — good to go.
   - `TIGHT: only … mm spare` — it fits, but with under 0.5 mm to spare. Measure your real cell.
   - `CELL DOES NOT FIT` — OpenSCAD will refuse to export until you fix it.
   It also prints the cavity size, the room around the cell, the total height and how far the hex
   key has to reach.
6. **Export**: **F6** (full render, can take a minute), then **F7** to save an `.stl`.
7. **Save your numbers**: click **+** on the preset bar and name them, or they're gone when you
   close the file.

## Quick reference

| You want to… | Change | Group |
|---|---|---|
| Use a different battery | `battery_t`, `battery_w`, `battery_l` | 1. Battery |
| Stand it up, lay it flat, stand it on end | `battery_orientation` | 1. Battery |
| Different tape or foam | `tape_t`, `foam_t` | 1. Battery |
| More room for the wires | `lead_end`, `lead_space` | 1. Battery |
| Match the case's outline | `plate_x`, `plate_y`, `plate_r` | 2. Plate outline |
| Rim fit in the front shell | `lip_outer_x`, `lip_outer_y`, `lip_h`, `lip_slop`, `lip_wall` | 3. Rim |
| Screw positions | `screw_dx`, `screw_dy` | 4. Screws |
| Tower height (how hard it presses the board) | `tower_drop` | 4. Screws |
| Holes too tight or loose on your printer | `hole_slop` | 4. Screws |
| Plug fit, or no plug recesses | `plug_interference`, `plug_recess` | 4c. Hole plugs |
| Grip ribs | `grip_depth`, `grip_style` | 5b. Grip |
| Export plugs instead of the plate | `part` | 6. Output |
| Desk stand: screen angle, box size | `desk_stand`, `stand_angle`, `stand_front_min`, `box_floor` | 7. Desk stand |
| Desk stand: how the head fits the box, lock screws, collar | `pocket_wall`, `pocket_clear`, `stand_ledge`, `lock_spread`, `lock_top_bottom`, `lock_pad`, `collar_h` | 7. Desk stand |
| See the battery in the preview | `show_battery` | 6. Output |

The sections below show what each of these is on the part.

## Battery

A cell's size code reads thickness, width, length: **103035** is 10 × 30 × 35 mm. Enter the
**real** size if you can measure it, including the little circuit board folded over at the wire
end — cheap cells often run half a millimetre over their listing.

`battery_orientation` sets how it sits:

| **edge** — on its long edge | **flat** — on its face | **end** — upright on its end |
|---|---|---|
|  |  |  |
| For cells up to about 37 mm long | For small square cells | Any length: the plate grows taller |

Why not just lay a long cell flat? The screws pass through 24 mm apart across the case, so a
wide cell would sit on them. Standing it up makes it only as wide as it is thick.

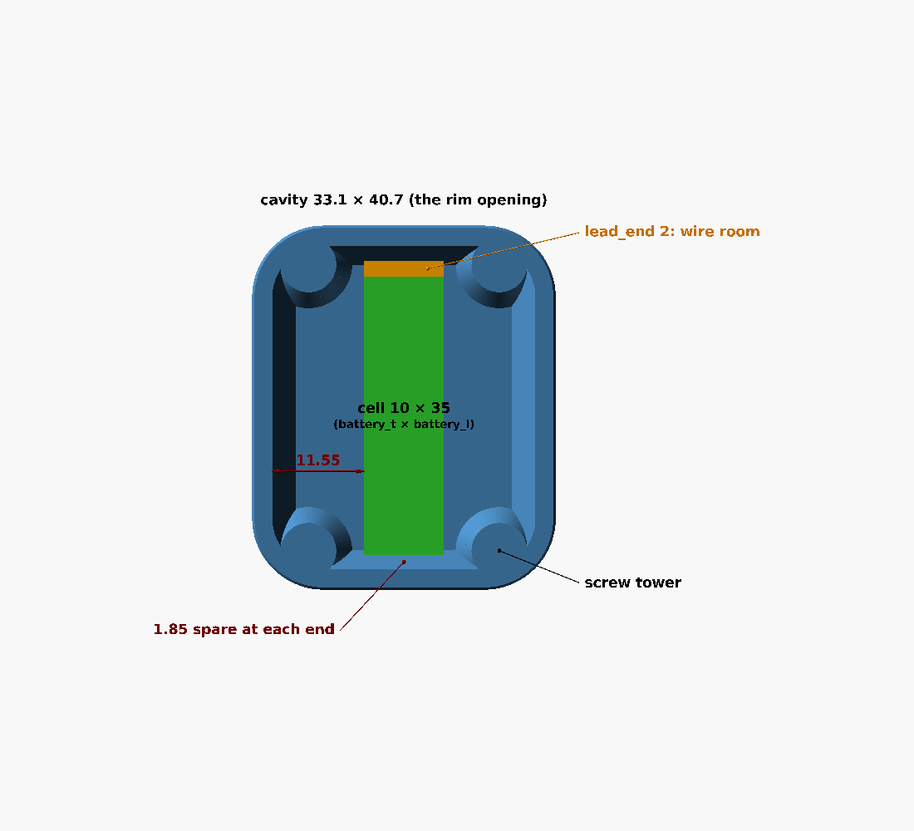
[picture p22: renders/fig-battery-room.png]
Top view of the default: the cell, its wire room and the clearances


| Field | What it does |
|---|---|
| `tape_t` | Thickness of the VHB tape under the cell (1 mm tape measures about 1.1) |
| `foam_t` | Foam on top of the cell |
| `lead_end` | Room kept free past the wire end of a flat or edge cell (orange above) |
| `lead_space` | Room above the cell for wires and plug — used for a cell on its end, whose wires come out the top |
| `extra_clearance` | A little air so nothing is squeezed |

The plate's depth follows from all of these automatically.

## Outline and screw positions

These come from Waveshare's own drawings and should already be right.

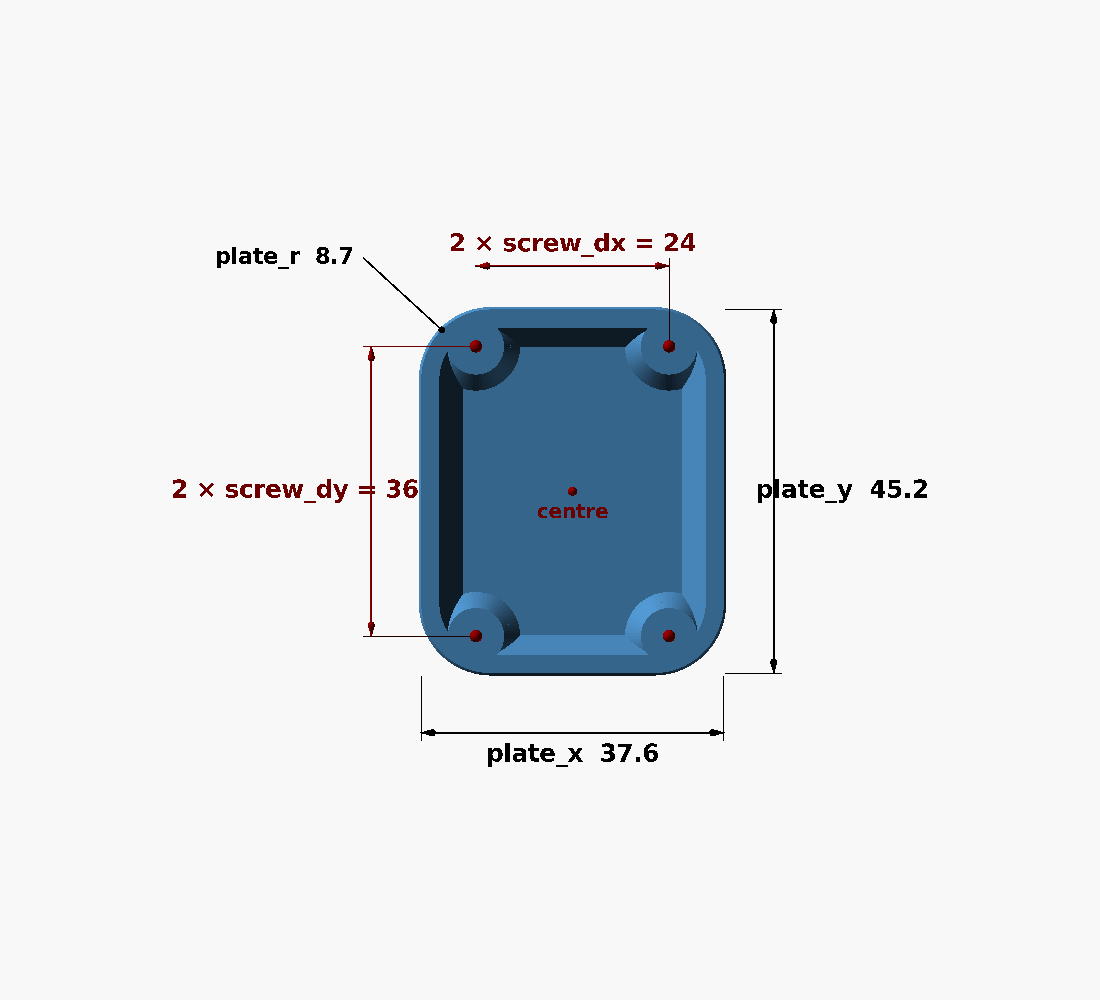
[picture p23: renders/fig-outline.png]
Outline and screw spacing


| Field | What it is | How to measure it on the stock cover |
|---|---|---|
| `plate_x`, `plate_y` | Outside width and length | Straight across |
| `plate_r` | Corner radius | Roughly how round the corners are |
| `screw_dx`, `screw_dy` | Centre to screw-hole centre, across and along | Hole to hole, then halve |

## Rim

The rim is the band on top of the wall that slides into the front shell. Its size is an
estimate from photos, so it's the thing most worth checking against the stock cover.

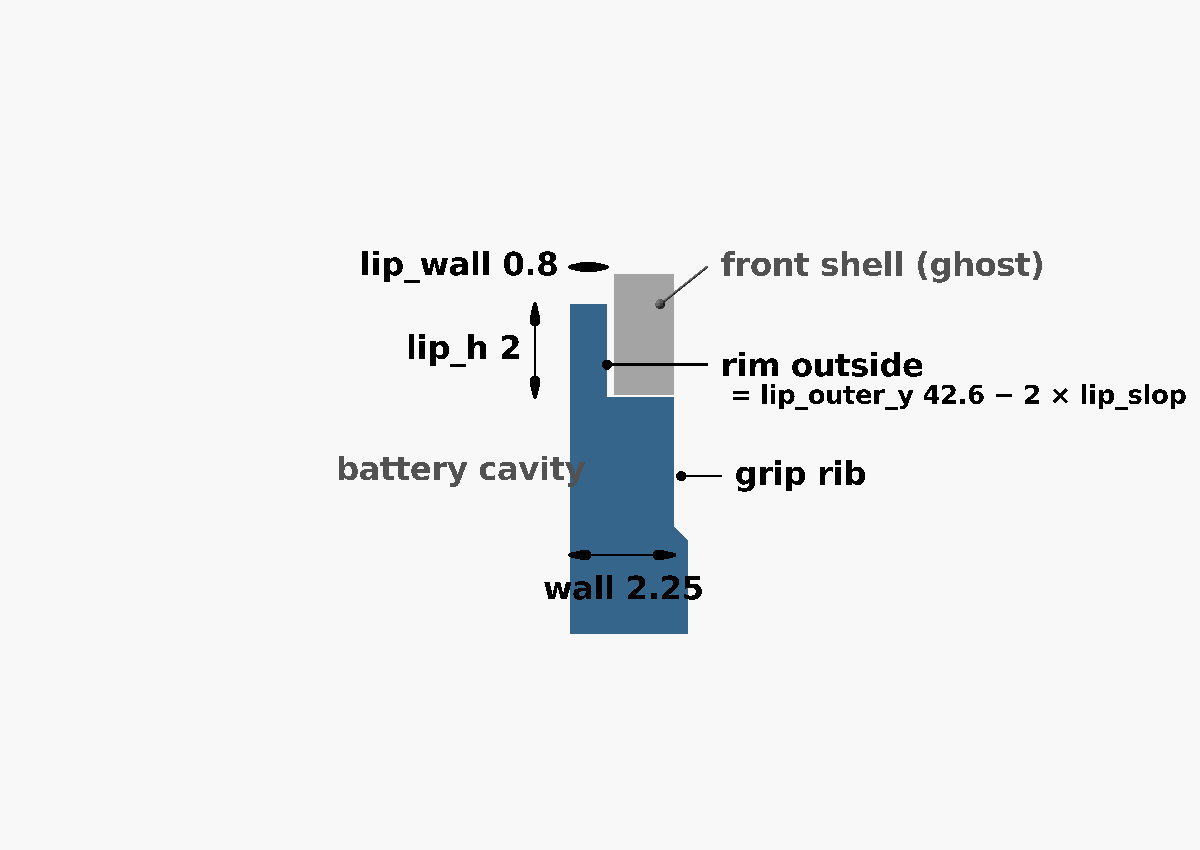
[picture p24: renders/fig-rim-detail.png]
The rim and the front shell's wall


| Field | What it is | Change it when |
|---|---|---|
| `lip_outer_x`, `lip_outer_y` | Outside size of the rim | Measure the stock rim's outside |
| `lip_h` | How tall the rim stands | Measure the stock rim |
| `lip_slop` | Taken off the outside so it isn't a press fit | Bigger = looser |
| `lip_wall` | Thickness of the rim | Thinner gives the battery a little more room (0.6 opens a 40 mm cell's space to 41.1) |
| `mic_slots`, `mic_slot_x`, `mic_slot_w` | Slots in the rim behind the front shell's speaker/mic notch: 4 mm wide, 8.5 mm off centre on both short sides | If the notch on your shell sits elsewhere, move `mic_slot_x` to its centre |

## Screw towers

Each screw goes up a hollow tower from the back. Its head sits under a 2 mm **seat** at the top,
and the tower's flat top presses on the board's brass standoff, level with the front shell's
edge.

Top of a screw tower

| Field | What it is | Change it when |
|---|---|---|
| `tower_drop` | How far below the rim top the towers stop (negative = above). 2, the rim's height, puts the tower tops at the seam, where the standoffs end | A gap at the seam: raise it by the gap. Board loose: lower it |
| `head_seat` | Plastic between screw head and standoff | Rarely; it sets the screw length (2 + how far the screw goes into the standoff) |
| `nut_pad_h`, `nut_pad_d` | Optional raised pad around the standoff (0 = flat top, the default) | Only if the tower top would press on parts beside a standoff |
| `hole_slop` | Extra on every hole, since printers make holes small | Screw head or hex key tight in the tower: raise by 0.1 |
| `bridge_skin` | The thin skin closing each tower for printing (0.4 mm, two layers) | Thicker if it sags; 0 for none (then a small overhang instead) |

## Hole plugs

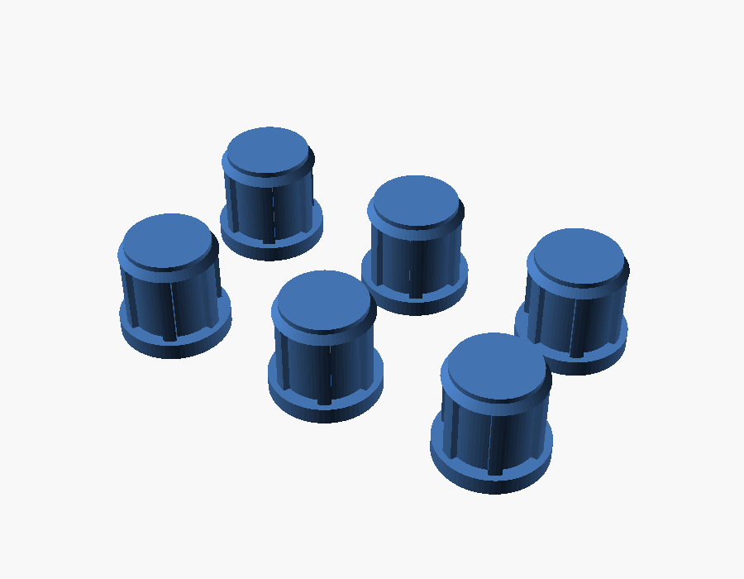
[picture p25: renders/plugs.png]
The plugs


| Field | What it does |
|---|---|
| `plug_interference` | How tight the press fit is: raise if they fall out, lower if they won't go in (steps of 0.05) |
| `plug_recess` | Untick for a plain back with no recesses (and no plugs) |
| `plug_cap_gap` | The gap around each cap for prying it out |
| `plug_count` | How many to print |

To export just the plugs, set `part` (group 6) to `plugs`; `both` shows them beside the plate.

## Grip ribs

| `grip_depth = 0` | `grip_depth = 0.3` (default) | `grip_depth = 0.5` |
|---|---|---|
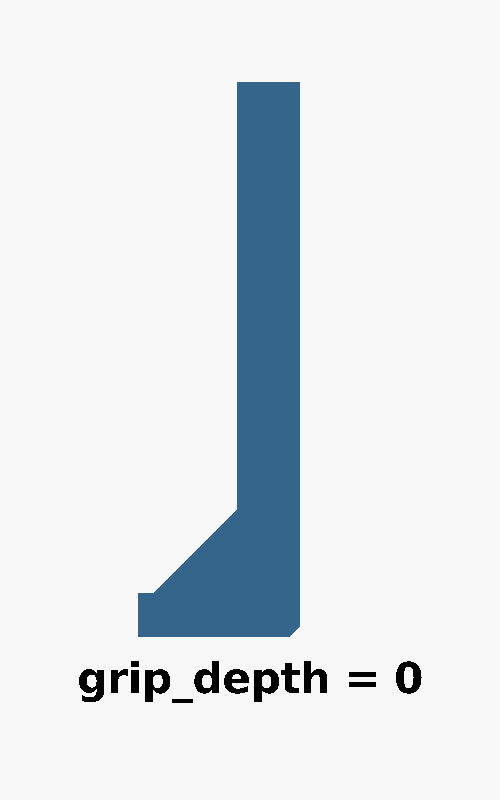
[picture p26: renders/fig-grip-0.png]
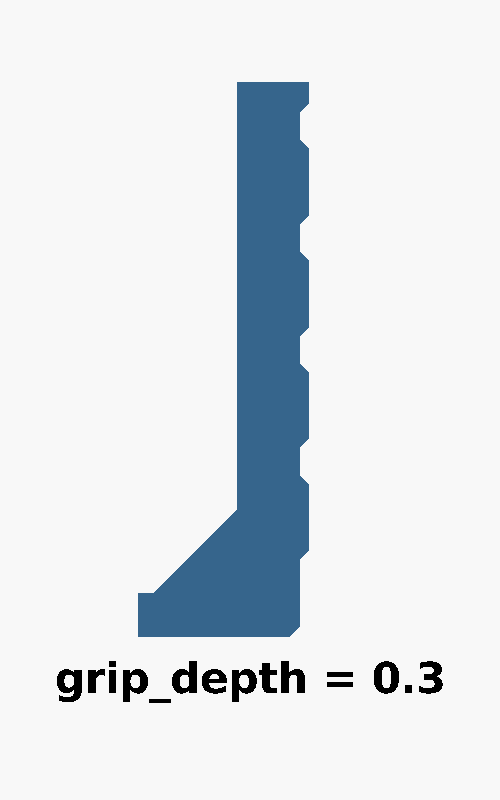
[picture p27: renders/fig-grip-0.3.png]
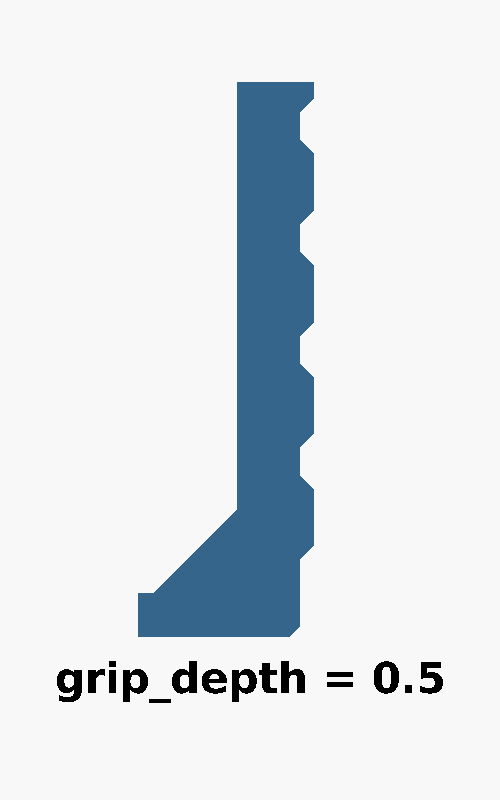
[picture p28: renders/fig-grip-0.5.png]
|  |  |  |

`grip_depth` is how far the ribs stand out, 0 to 0.5 mm (0 = smooth walls). `grip_style` also
offers `honeycomb` (raised hexagons) and `nubs` (raised squares). `grip_size`, `grip_gap` and
`grip_margin` set the rib height, spacing and how far they stay from the bed and the seam.

## Measuring the stock cover

The outline and screw positions are from Waveshare's data. These few couldn't be seen in any
source; measuring them on the original black cover makes a keeper fit first time.

| Measure | Put it in |
|---|---|
| How tall the rim stands | `lip_h` |
| The rim's outside width and length | `lip_outer_x`, `lip_outer_y` |
| How far the board's standoffs end from the front shell's edge (2 = level with it, as measured) | `tower_drop` (rim height + that distance) |
| Rim top down to the floor inside | `stock_clear` (only affects reported numbers) |
| How far a stock screw goes into its standoff | Choosing screw length — [DESIGN.md](DESIGN.md#screws) |

## Desk stand

Pick **Desk stand: head (fits every box)**, **Desk stand: head, no collar** or **Desk stand:
box for …** from the preset drop-down, or tick `desk_stand` (group 7) on any version. `part`
then chooses the piece: `plate` gives the **head**, `box` the **box**, and `stand` shows both
put together (for looking at, not exporting). The battery fields (group 1) work exactly as for
the plate: set your cell and orientation, and the box grows to fit it. `show_battery` ghosts it
in the box. The head doesn't depend on the battery, so one head fits every box.

### The head presets

The boxes are built from the model's defaults. The two head presets change a few fields on top,
for a snugger head that fits those same boxes ([DESIGN.md](DESIGN.md#the-collar-head) says why):

| Field | Default | Head presets | Effect |
|---|---|---|---|
| `lip_h` | 2.0 | 1.5 | A shorter rim, so it doesn't hold the front shell up |
| `stock_clear` | 3.9 | 3.4 | Drops with `lip_h`, so the part of the head in the box stays 3.5 mm |
| `tower_drop` | 2.0 | 2.0 | With the shorter rim, the tower tops now stop 0.5 mm below the seam |
| `pocket_clear`, `lip_slop` | 0.15 | 0.05 | Tighter gaps to the box and inside the shell |
| `lock_pad`, `stand_ledge` | 1.0 | 1.1 | On the head these only deepen its lock-pad notches, to match the wider head |
| `lock_block_join` | off | on | Joins each lock block to its nearest tower |
| `head_clear` | 0.6 | 0.4 | A slightly tighter bore round each screw head, which leaves 0.83 mm of wall between the bore and the head's rounded corner |
| `collar_h` | 0 | 3 (0 in "no collar") | The collar |

Change head fields in a head preset, and box fields in a box preset. Don't copy the head's
`lock_pad` or `stand_ledge` into a box preset: there they change the box's pads and ledge.
The box presets do set `collar_h` (3): it gives the box's band the 45° ramp the collar's
underside nests on. Set it to 0 in a box preset to make a box for the no-collar head.

### The box

The desk stand from the side, as it sits: its size and angle

| Field | What it is | Change it when |
|---|---|---|
| `stand_angle` | How far the screen leans back from upright, 10–45° | Taste. More lean makes the box longer |
| `stand_front_min` | The shortest the box's top may be (the short wall under the USB-C edge) | The box is as short as the battery allows, but never shorter than this |
| `box_floor` | Thickness of the box's floor | Rarely |

The cell always lies on the long flat wall the box rests on, where there's most room; pack the
space around it with foam. `battery_orientation` names how the cell stands in the box as it's
printed (on its floor): `end` makes the longest box, `flat` the shortest.

| 103035 on edge | 802525 flat | 104050 on end |
|---|---|---|
|  |  |  |

### How the head fits the box

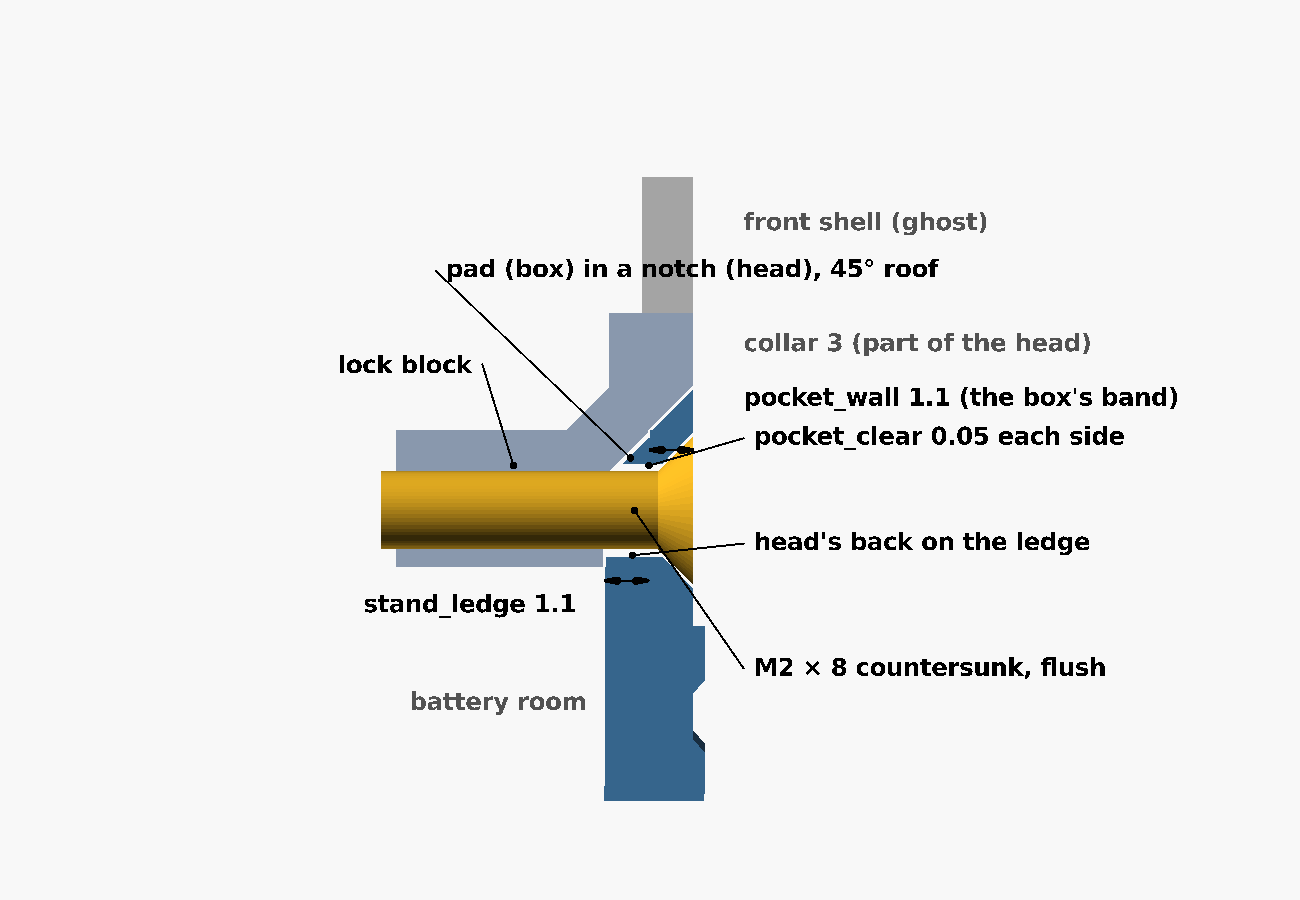
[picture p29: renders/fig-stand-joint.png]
Where the head sits in the box, cut through a side wall at a lock screw


| Field | What it is | Change it when |
|---|---|---|
| `pocket_wall` | The box's wall round the head at its rim, which the front shell sits on (0.8–1.3). The head is this much (plus `pocket_clear`) smaller than the case each side | Rarely. The default 1.1 is already the most the head's rim allows; go thinner only to give the head more room |
| `pocket_clear` | Gap between the head and the box, each side (0.05–0.25). The head presets use 0.05, the tightest | Head won't go in: raise by 0.05 in the head preset |
| `stand_ledge` | Width of the step inside the box the head's back rests on | Wider is firmer but leaves less room for the battery (the 104050 box uses 0.8) |
| `lock_spread` | Distance between the two lock screws on each side (0 = one per side, in the middle) | Rarely; 14 keeps them on the flat part of the side |
| `lock_top_bottom` | One more lock screw in the top and one in the bottom, diagonally opposite so they miss the battery slot | Untick for side screws only |
| `lock_pad` | How far the thicker pad at each lock screw reaches into a notch in the head's edge, at most `stand_ledge` (1.0; the head presets use 1.1 so the notch matches the wider head) | 0 for no pads (then the screws seat in the 1.1 mm band alone) |
| `collar_h` | A collar on the head between the box and the front shell (0 = none). The head grows this much taller and, above the box, widens to the case outline. On a box it adds the 45° ramp the collar nests on; nothing else about the box changes | To lift the board further above the lock blocks, or to print a coloured band that tells units apart |
| `collar_chamfer` | Slopes the collar's underside at 45° so it prints without sagging, and gives the box's band a matching ramp (on by default) | Off only for a flat-bottomed collar, which then overhangs about 1.2 mm |
| `lock_block_join` | Fill between each lock block and its nearest screw tower, up to the block's top (off by default) | On, to get rid of the narrow V between a block and the tower's flare |

The head can't shrink past its own rim, so `pocket_wall` + `pocket_clear` together can't go above
1.35; the console stops with `RIM IS LARGER THAN THE HEAD` if they do. The box's outside is always
the case outline (`plate_x`, `plate_y`, `plate_r`), so the front shell sits flush whatever these
are.

### What the console tells you

The head's size; how far below the seam its tower tops and lock blocks stop, and the screw seat;
the collar, if any; the box's size as it lies on the table; the whole unit's size with the display
on; the room each side of the cell; and the screws to buy, with the display screws' length
worked out for that head (M2 × 5 with the collar, M2 × 4 without). The same `TIGHT` and
`DOES NOT FIT` warnings as the plate, and it refuses to export a box the cell doesn't fit.

### Measuring for the desk stand

| Measure | Why |
|---|---|
| The front shell's outside, if it isn't flush with the box | The box's outside is the case outline: correct `plate_x`, `plate_y`, `plate_r` ([outline](#outline-and-screw-positions)) |
| Where the board's `BAT` socket is, and which way its mouth faces | The head's slot sits just in front of it, taken from Waveshare's 3D model ([figure](renders/fig-stand-head.png)). If your board differs, the slot's position is in `head_holes()` in the `.scad` — the one place you'd edit code |

Grip ribs (group 5b) go round the box too, clear of its angled end. The head has none: it sits
inside the box, and only its collar shows.

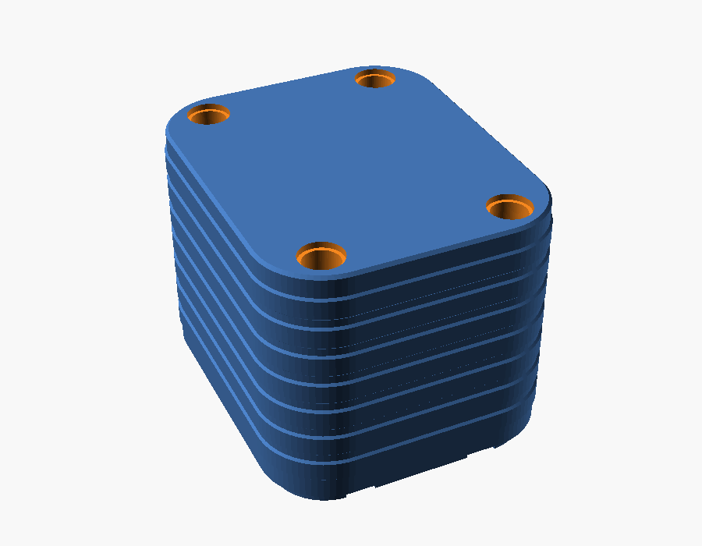
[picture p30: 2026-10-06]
renders/back.png

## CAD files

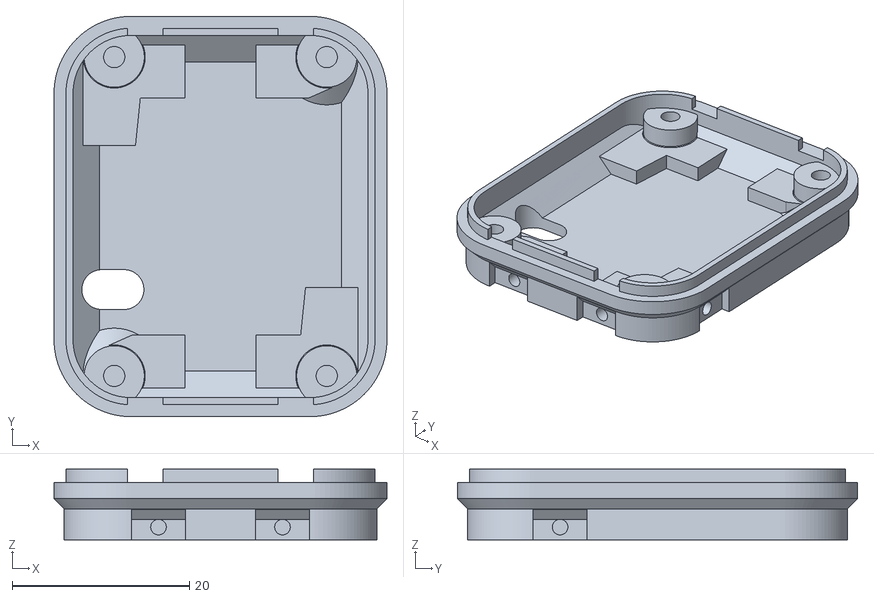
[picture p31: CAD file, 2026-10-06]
amoled18_stand_head.stl
37.6 x 45.2 x 8.00

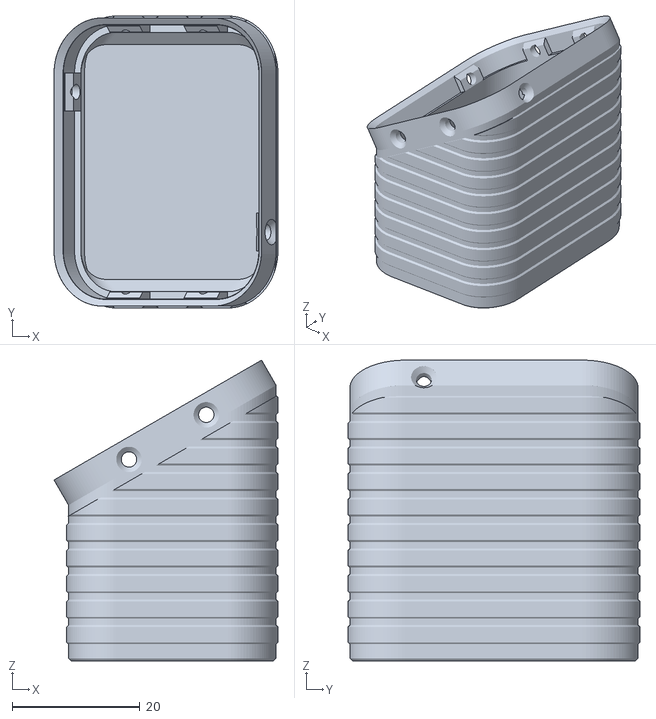
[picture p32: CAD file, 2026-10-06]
amoled18_stand_box_103035_edge.stl
35.1 x 45.8 x 47.2

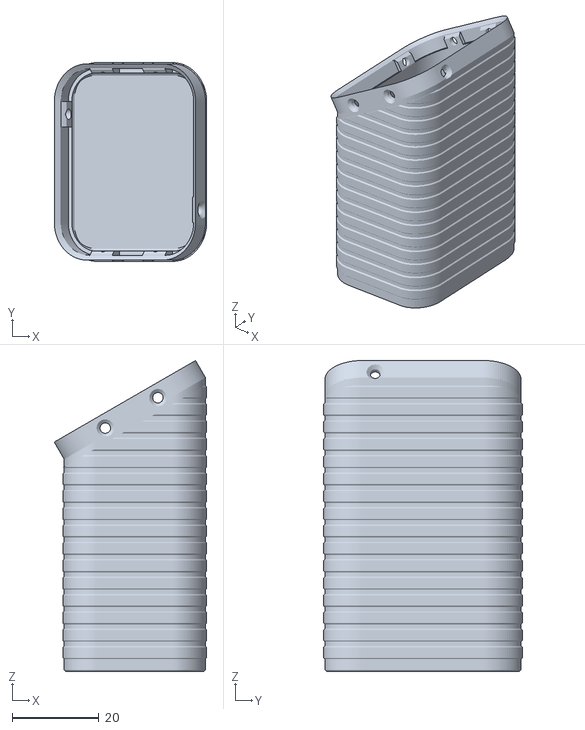
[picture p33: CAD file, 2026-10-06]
amoled18_stand_box_104050_end.stl
35.1 x 45.8 x 71.7

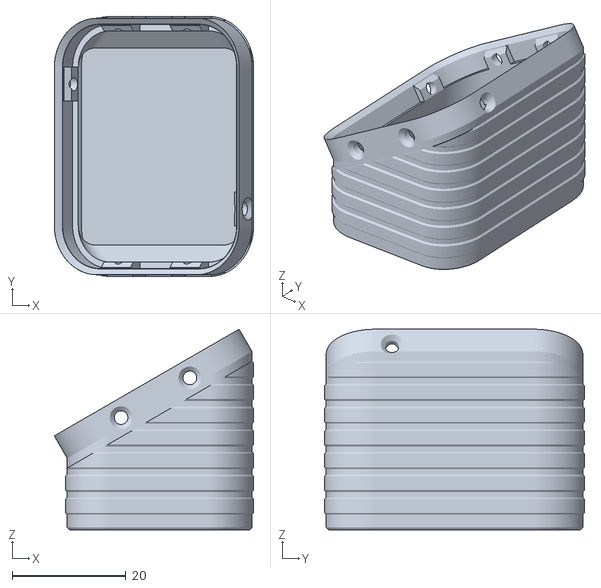
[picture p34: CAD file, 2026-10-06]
amoled18_stand_box_802525_flat.stl
35.1 x 45.8 x 35.3

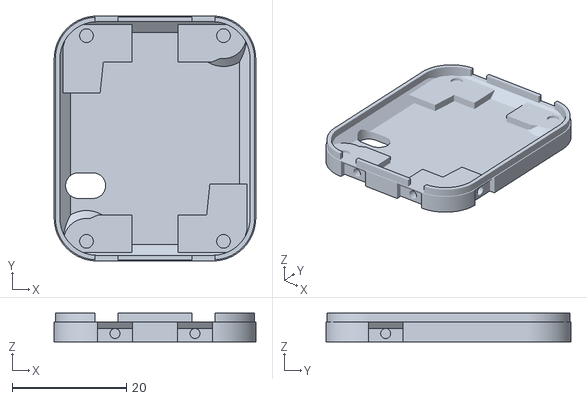
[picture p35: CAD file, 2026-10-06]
amoled18_stand_head_no_collar.stl
35.3 x 42.9 x 5.00

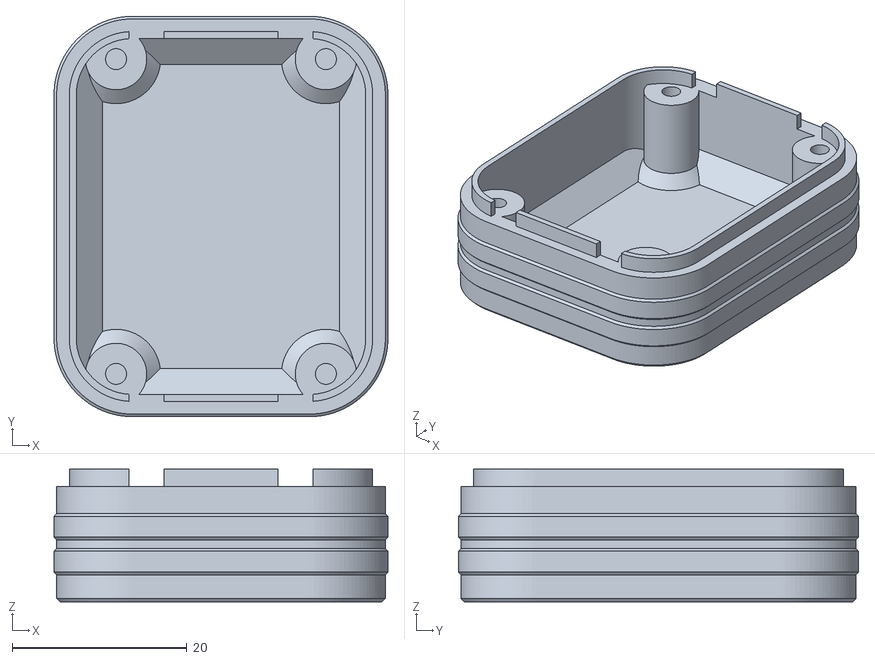
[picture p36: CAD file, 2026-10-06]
back_plate_802525_400mAh_flat.stl
38.2 x 45.8 x 15.2

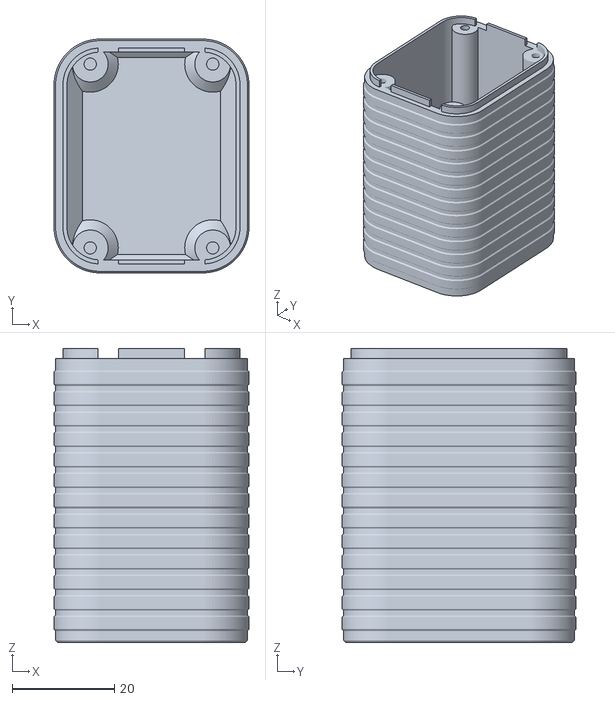
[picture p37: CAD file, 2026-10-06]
back_plate_104050_2400mAh_end.stl
38.2 x 45.8 x 57.6

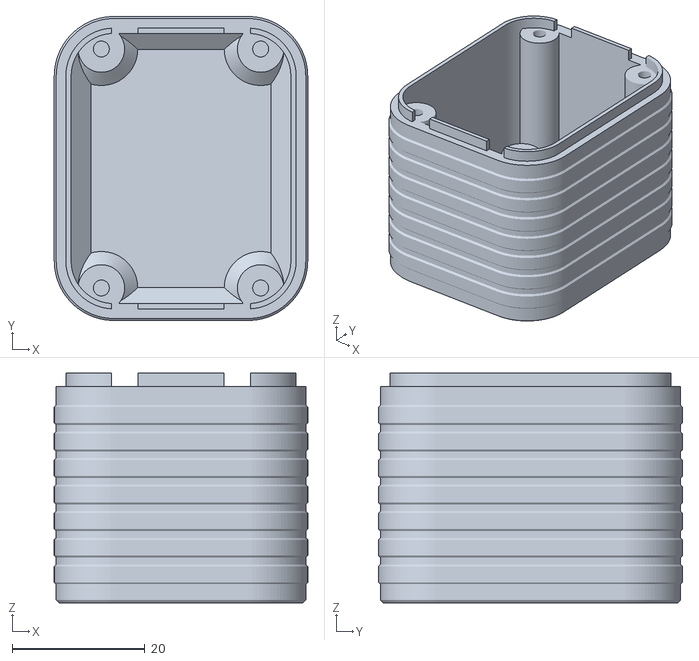
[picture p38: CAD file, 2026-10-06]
back_plate_103035_1000mAh_edge.stl
38.2 x 45.8 x 34.6

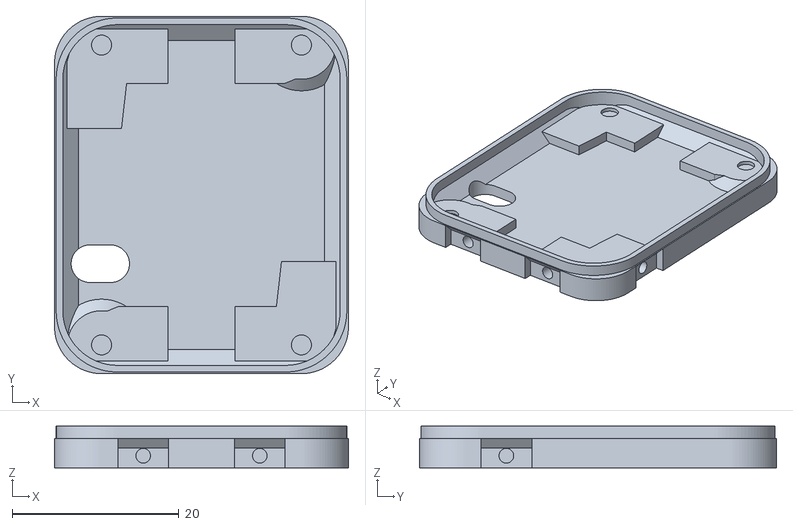
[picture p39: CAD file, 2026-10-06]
amoled18_stand_head_allan_fitment.stl
35.3 x 42.9 x 5.00

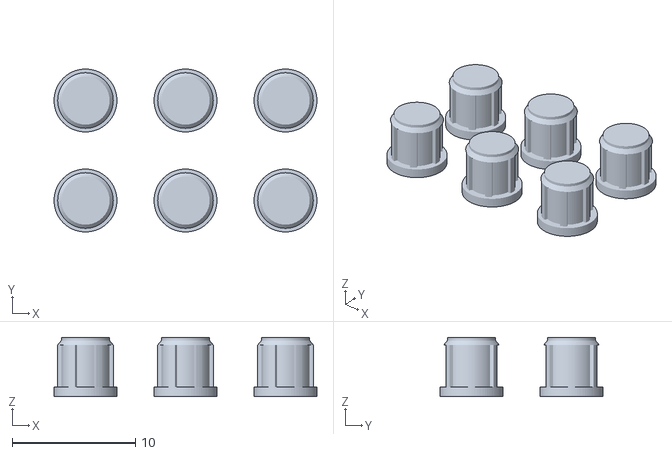
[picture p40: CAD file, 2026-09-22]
amoled18_hole_plugs.stl
21.3 x 13.2 x 4.80

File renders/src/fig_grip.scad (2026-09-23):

// A slice through the side wall at y = 0, seen from -y, showing the grip ribs.
// Render with -D grip_depth=...
include <../../amoled18_back_plate.scad>
use <annot.scad>
show_part = false;
$fn = 48;
color("SteelBlue") render() intersection() {
    back_plate();
    translate([13, 0, -0.1]) cube([8, 0.4, 20]);
}
label([17, 0, -1.6], str("grip_depth = ", grip_depth), "front", 1.1);

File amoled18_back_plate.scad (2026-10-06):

// =====================================================================
// PARAMETRIC BACK PLATE
// Waveshare ESP32-S3-Touch-AMOLED-1.8  (replaces the stock black cover)
//
// The stock back is a flat plate with a shallow rim. All ports, buttons
// and the mic live in the FRONT shell, so this part is solid except for
// the battery cavity and four screw holes.
//
// Group 7 builds a two-part desk stand instead: a thin head that screws to
// the display, and a battery box it sinks into (see DESIGN.md).
//
// EVERY dimension is adjustable. In OpenSCAD open
//     Window > Customizer
// and the parameters appear as labelled fields and sliders, grouped by
// section. No code editing required.
//
// Workflow:  set values  >  F5 preview  >  F6 render  >  F7 export STL
//
// NOTE ON SCREWS: each screw sits in a hollow tower. Its head rests near
// the top, so the tower presses on the board's standoff as the stock cover's
// posts do, and a short standard socket head screw is enough. Drive it
// down the tower with a long hex key.
//
// Units: millimetres.   OpenSCAD is free at openscad.org
// =====================================================================


/* [1. Battery] */

// Cell thickness (the first number in a size code: 103035 is 10)
battery_t = 10.0;   // [2:0.1:25]
// Cell width (103035: 30). On edge it's the height; on end it runs along the case
battery_w = 30.0;   // [10:0.5:60]
// Cell length (103035: 35). Along the case, or the height when on end
battery_l = 35.0;   // [10:0.5:60]
// flat = lying on its face. edge = standing on its long edge, which fits long cells.
// end = standing upright on its end: any length fits, the plate just gets taller.
battery_orientation = "edge";  // [flat, edge, end]
// Double-sided tape under the cell (VHB 1mm measures about 1.1)
tape_t = 1.1;       // [0:0.1:3]
// Foam padding above the cell
foam_t = 1.5;       // [0:0.1:5]
// Room above the cell for its wires and plug (the circuit board end faces up)
lead_space = 0.0;   // [0:0.5:10]
// Room past one end of the cell for its wires, when they leave from an end (flat and edge)
lead_end = 2.0;     // [0:0.5:8]
// Extra air so nothing is ever compressed
extra_clearance = 0.4;  // [0:0.1:2]


/* [2. Plate outline] */

// Defaults from Waveshare's dimension drawing: case 37.6 x 45.2 mm,
// corner radius fitted to the drawing at about 8.7 mm. See README.md.


// Overall width of the plate
plate_x = 37.6;     // [20:0.1:80]
// Overall height of the plate
plate_y = 45.2;     // [20:0.1:80]
// Outer corner radius
plate_r = 8.7;      // [0.5:0.1:20]
// Thickness of the flat back panel
plate_t = 1.6;      // [0.8:0.1:5]
// Small 45 degree chamfer on the flat back edge, against elephant's foot (0 = sharp)
edge_chamfer = 0.4;  // [0:0.1:1.5]


/* [3. Rim that enters the front shell] */

// Rim defaults assume a ~1.3 mm front-shell wall, estimated from photos.
// These are the least certain numbers in the file: measure them.


// How to define the rim outline.
//   inset    = stepped in from the plate edge by lip_inset
//   absolute = you type its outside width and length directly
lip_mode = "absolute";  // [inset, absolute]

// -- absolute mode: measure the OUTSIDE of the stock rim --
// Rim outside width
lip_outer_x = 35.0;  // [10:0.1:80]
// Rim outside length
lip_outer_y = 42.6;  // [10:0.1:80]
// Rim outside corner radius
lip_outer_r = 7.4;   // [0.5:0.1:20]

// -- inset mode only --
// How far the rim steps in from the outer edge
lip_inset = 1.4;     // [0:0.1:6]

// -- both modes --
// How tall the rim stands above the floor
lip_h = 2.0;         // [0:0.1:8]
// Width of the rim wall (how thick the band is)
lip_wall = 0.8;      // [0.4:0.1:4]
// Slots in the rim behind the front shell's speaker/mic notch (a U in the shell's edge on
// one short side, about 8.5 mm off centre), so the rim doesn't close it off. Cut on both
// short sides at both offsets, so they clear it whichever way round the part goes on; the
// shell hides them.
mic_slots = true;
mic_slot_x = 8.5;    // [0:0.5:16]
mic_slot_w = 4.0;    // [1:0.5:8]
// Clearance taken off the outside so it is not a press fit
lip_slop = 0.15;     // [0:0.05:0.6]
// Inside depth of the STOCK cover (rim top down to the floor)
stock_clear = 3.9;   // [1:0.1:15]


/* [4. Screws] */

// Hole positions come from the PCB's mounting holes in Waveshare's 3D
// model: 24.0 x 36.0 mm apart, centred on the board.


// Centre of plate to hole centre, across X
screw_dx = 12.0;    // [5:0.1:40]
// Centre of plate to hole centre, across Y
screw_dy = 18.0;    // [5:0.1:40]
// Thread size drives the default hole sizes
screw_size = "M2";  // [M1.6, M2, M2.5, M3, Custom]
// Optional raised pad around the standoff, if the flat tower top ever needs to
// stand clear of parts on the board near a standoff
nut_pad_d = 4.5;    // [3:0.1:7]
// How far that pad stands above the rest of the tower top (0 = flat top, the default)
nut_pad_h = 0.0;    // [0:0.1:2]
// Room around the head so it slides down the tower and a hex key reaches
head_clear = 0.6;   // [0:0.1:2]
// Plastic between the screw head and the board's standoff, at the top of each tower
head_seat = 2.0;    // [0.6:0.1:5]
// Wall around the screw head in each tower
tower_wall = 1.2;   // [0.8:0.1:3]
// How far below the rim top the towers stop; negative = they stand above it.
// The board's brass standoffs end level with the front shell's edge (measured
// on a real unit), so the towers stop at the seam: tower_drop = lip_h.
tower_drop = 2.0;   // [-5:0.1:10]
// Thin skin (two layers at 0.2 mm) closing the top of each tower's bore so it prints as a bridge;
// poke it through with the screw. 0 = none
bridge_skin = 0.4;  // [0:0.05:0.8]

// Printer hole allowance (holes print undersize; 0.2 suits most FDM)
hole_slop = 0.2;    // [0:0.05:0.6]

/* [4b. Custom screw sizes - used only when screw_size is Custom] */
custom_shaft_d = 2.0;   // [1:0.1:6]
// Socket head diameter
custom_head_d = 3.8;    // [2:0.1:10]
// Socket head height
custom_head_t = 2.0;    // [0.4:0.1:6]


/* [4c. Hole plugs - press-fit caps that hide the tower openings] */

// Recess each tower opening so a plug sits flush (off = no recess)
plug_recess = true;
// Recess and plug cap depth
plug_cap_t = 0.8;       // [0.4:0.1:2]
// How much wider the recess is than the bore
plug_cap_extra = 1.0;   // [0.6:0.1:3]
// Length of the plug's shank inside the bore
plug_len = 4.0;         // [1:0.5:10]
// Press fit: how far the ribs stand over the printed bore. Raise if loose, lower if tight
plug_interference = 0.1;  // [-0.2:0.05:0.4]
// Gap around the cap in its recess, so a knife tip can pry the plug out
plug_cap_gap = 0.15;    // [0:0.05:0.5]
// Plugs to print (4 plus spares)
plug_count = 6;         // [1:1:12]


/* [5. Battery cavity] */

// The whole inside is hollow apart from the four screw towers; pad gaps
// with foam.
// The walls rise straight up to the rim, so the cavity is the rim opening
// and the rim wall below sets how much room there is.
// 45 degree chamfer where the walls meet the floor, to brace the walls.
// Shrinks by itself on any wall the cell sits close to.
wall_chamfer = 3.0;     // [0:0.5:8]
// 45 degree flare where each screw tower meets the floor. Also shrinks near the cell
tower_flare = 2.0;      // [0:0.5:6]


/* [5b. Grip texture on the outside walls] */

// Raised texture so small hands don't drop it. All shapes slope 45 degrees
// underneath, so they print without supports.
grip_style = "ribs";    // [none, honeycomb, nubs, ribs]
// How far the texture stands out from the wall, in mm. 0 = smooth walls
grip_depth = 0.3;       // [0:0.05:0.5]
// Size of each hexagon or square (across)
grip_size = 3.0;        // [1.5:0.1:6]
// Gap between hexagons or squares, or between ribs
grip_gap = 1.0;         // [0.4:0.1:4]
// Keep the texture this far from the bed edge and from the seam at the top
grip_margin = 1.5;      // [0.5:0.5:5]


/* [7. Desk stand (two parts)] */
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

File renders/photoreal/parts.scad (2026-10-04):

// Pieces for the photoreal shots (make_photoreal.sh), each exported as its own STL.
// The printed parts are exported in their PRINT frames so Blender's layer lines run the way
// the printer lays them; the markers carry each part's pose into the scene.
include <../../amoled18_back_plate.scad>
show_part = false;
which = "plate";

// A dot at the origin and dots 1, 2 and 3 mm along x, y and z; marker.py reads the pose back.
module marker() for (p = [[0, 0, 0], [1, 0, 0], [0, 2, 0], [0, 0, 3]]) translate(p) cube(0.01, center = true);

// The stock front shell, from the seam up. It is not in Waveshare's STEP (that is the board and
// the panel only), so this is drawn from the case outline and the photos: the board hangs on
// standoffs that end at the seam, its back so_h above it, so the glass lands 0.15 under the
// shell's face. The openings sit where the STEP has the USB-C and the two buttons.
front_h = 11.5;
so_h = 4;
step_dz = so_h + 7.4;   // STEP z (board back at -7.4) -> height above the seam
module front_shell() difference() {
    rbox(plate_x, plate_y, front_h, plate_r);
    translate([0, 0, -1]) rbox(plate_x - 2.4, plate_y - 2.4, front_h - 0.5 + 1, plate_r - 1.2);
    hull() {
        translate([0, 0, front_h - 0.6]) linear_extrude(height = 0.01) rrect(29.9, 37.7, 3.2);
        translate([0, 0, front_h]) linear_extrude(height = 0.01) rrect(30.9, 38.7, 3.7);
    }
    translate([0, 0, front_h - 2]) linear_extrude(height = 2) rrect(29.9, 37.7, 3.2);
    translate([plate_x / 2 - 3, 0, step_dz - 6.15]) rotate([0, 90, 0])
        linear_extrude(height = 5) hull() for (dy = [-3.3, 3.3]) translate([0, dy]) circle(d = 3.4);
}
module shell_buttons() for (sy = [-1, 1])
    translate([plate_x / 2 - 0.3, sy * 10.5, step_dz - 5.5]) rotate([0, 90, 0])
        linear_extrude(height = 0.9) hull() for (dy = [-1.6, 1.6]) translate([0, dy]) circle(d = 1.9);

// The lock screws: flush countersunk M2 x 8 with a cross recess, in the box's print frame.
module lock_screws() multmatrix(m_head) for (p = lock_pts)
    translate(p[3] != 0 ? [p[0], p[3] * plate_y / 2, lock_z] : [p[2] * plate_x / 2, p[1], lock_z])
        inward([p[2], p[3]]) difference() {
            union() {
                cylinder(d1 = 3.8, d2 = 2, h = 1.0, $fn = 48);
                cylinder(d = 2, h = 8, $fn = 32);
            }
            for (a = [0, 90]) rotate(a) translate([-1.1, -0.25, -0.01]) cube([2.2, 0.5, 0.7]);
        }

if (which == "plate") back_plate();
if (which == "marker_plate") translate([0, 0, body_h]) marker();
if (which == "box") stand_box();
if (which == "marker_box") stand_pose() marker();
if (which == "marker_head") stand_pose() stand_head_pose() marker();
if (which == "marker_seam") stand_pose() stand_head_pose() translate([0, 0, body_h]) marker();
if (which == "shell") front_shell();
if (which == "buttons") shell_buttons();
if (which == "screws") lock_screws();

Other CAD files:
renders/src/annot.scad
renders/src/fig_back_plugs.scad
renders/src/fig_battery_room.scad
renders/src/fig_cutaway.scad
renders/src/fig_floor_detail.scad
renders/src/fig_outline.scad
renders/src/fig_print_bed.scad
renders/src/fig_rim_detail.scad
renders/src/fig_stand.scad
renders/src/fig_stand_head.scad
renders/src/fig_stand_joint.scad
renders/src/fig_stand_print.scad
renders/src/fig_stand_side.scad
renders/src/fig_tower_bottom.scad
renders/src/fig_tower_top.scad
renders/src/fig_version.scad

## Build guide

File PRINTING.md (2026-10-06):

# Printing and assembly

> **Status:** Living · **Last verified:** 2026-10-06

Everything from buying parts to a finished unit. Back to the [README](README.md).

## 1. Get the parts

| Part | Notes |
|---|---|
| **Battery** | 3.7 V single-cell LiPo matching your version (103035, 802525 or 104050) with a **1.25 mm two-pin plug** — sold as "MX1.25", "Micro JST 1.25" or "PicoBlade". A 2.0 mm "JST PH" plug won't fit the board: swap the plug or use an adapter. |
| **4 × M2 × 4 socket head cap screws** | ISO 4762 / DIN 912, the round head with a hex socket. Don't go longer without reading [screw length](DESIGN.md#screws): too long presses on the display. |
| **1.5 mm hex key or driver** | Must reach down a 4.6 mm hole: about 35 mm for the default, 15 mm for the flat version, 60 mm+ for the tall one (the console gives each). A screwdriver-style hex driver is easiest. |
| **1 mm double-sided VHB tape** | Holds the battery to the floor. |
| **1.5 mm foam** | Thin craft or gasket foam, on top of the battery and in the gaps. |
| **2 mm drill bit** | Turned by hand, clears the thin skin at the top of each screw tower. |

## 2. Print

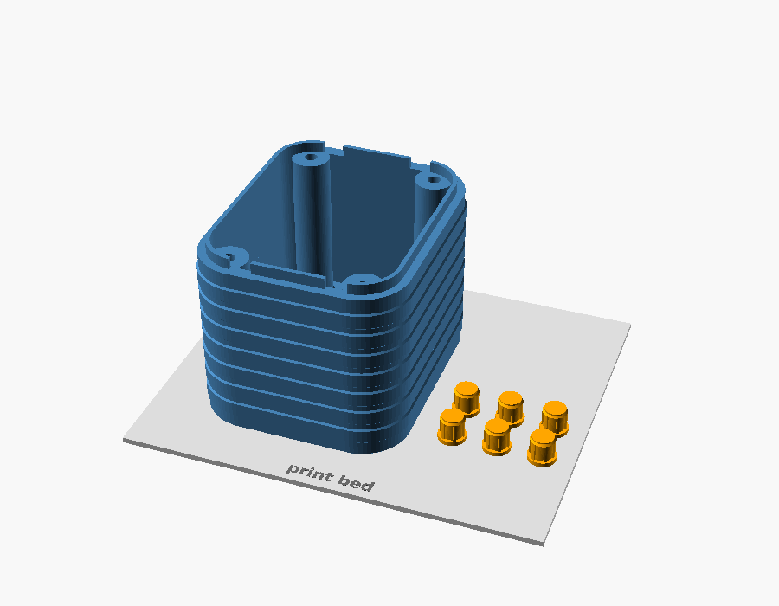
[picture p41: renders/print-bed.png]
How it sits on the bed: back face down, rim up, plugs caps-down


| Setting | Value |
|---|---|
| Orientation | Flat back face down, rim up — as the file loads. **No supports.** |
| Material | PETG (or ABS). PLA softens in a hot car. |
| Layer height | 0.2 mm |
| Walls / perimeters | 3 or more. The rim is 0.8 mm: check the slicer preview shows it solid (two lines). |
| Infill | 40 % or more |
| Plugs | As laid out in their file, flat caps down; same material if you want them to match. |

Everything that isn't straight up is sloped at 45° or less, so nothing needs support. The only
flat overhang is a thin skin closing the top of each screw hole, which bridges cleanly — and
which you clear in step 3.

Bottom of the wall on the bed

**Do a quick test print before a keeper**, and try it on the unit (steps 3–4). If anything is
off, [TROUBLESHOOTING.md](TROUBLESHOOTING.md) says which number to change.

## 3. Clear the screw towers

Each screw runs up a hollow tower, and its hole is closed at the top by a thin printed skin
(`bridge_skin`, two layers) so the printer can bridge it. Drill it through with a 2 mm bit turned
by hand; the screw alone may struggle.

Top of a screw tower: the thin layer to push through, the seat the screw head bears on, and the board's standoff above

## 4. Test-fit

With no battery in, set the plate on the front shell. The rim should slide in without forcing, and
the four towers should line up with the four brass standoffs on the board. The plate should sit
right down on the shell's edge with no gap; if it doesn't, see
[TROUBLESHOOTING.md](TROUBLESHOOTING.md#screws-and-towers).

The rim slides inside the front shell's wall

Check too that nothing on the board was resting on the stock cover's inner rails or raised block
(the speaker, for instance): this plate doesn't copy them.

## 5. Fit the battery

1. **Check the plug's polarity first.** Compare the battery's wires with the `+` and `−` marks
   beside the board's `BAT` socket. Cheap batteries don't agree on which is which; if it's
   reversed, swap the two pins in the plug with a needle before connecting.
2. **Tape it down**: VHB on the floor, battery on top, wire end toward the end with the orange
   wire room below. Trim the tape so it lies flat instead of climbing the sloped edges.
3. **Plug it in**, lay the foam on top, and pack a little foam in any gap so it can't shift.

Where the default cell stands, and its wire room

The default version cut open: tape (red), battery (green), foam (yellow)

## 6. Close it up

Seat the plate on the front shell. Drop a screw down each tower and turn it with the hex key
until snug — the screw head bears on the seat at the top of the tower, and the tower top presses
the board's standoff. Don't crank it.

Cut through two screw towers

## 7. Plugs (optional — not for babies)

Press one into each opening on the back until the cap sits flush. To reach a screw again, pry a
plug out with a knife tip in the small gap around its cap.

| Without plugs | With plugs |
|---|---|
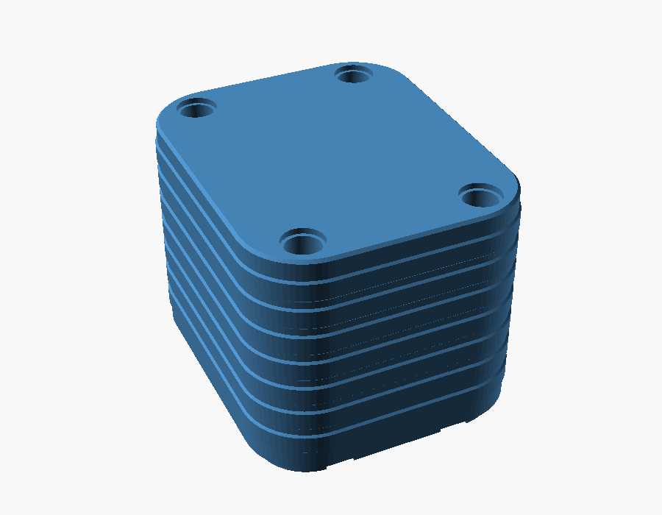
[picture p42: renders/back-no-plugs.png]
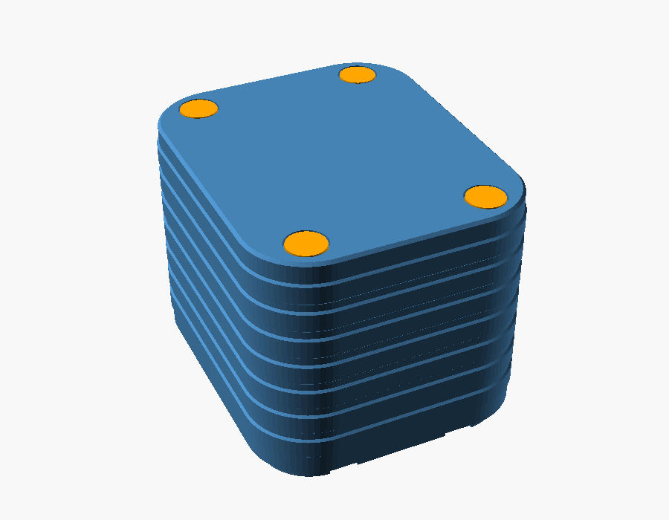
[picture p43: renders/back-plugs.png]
|  |  |
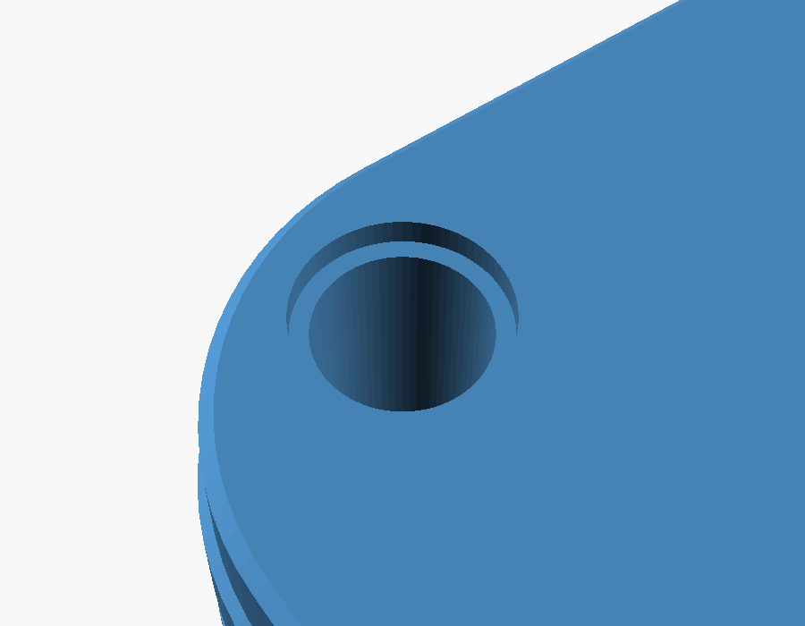
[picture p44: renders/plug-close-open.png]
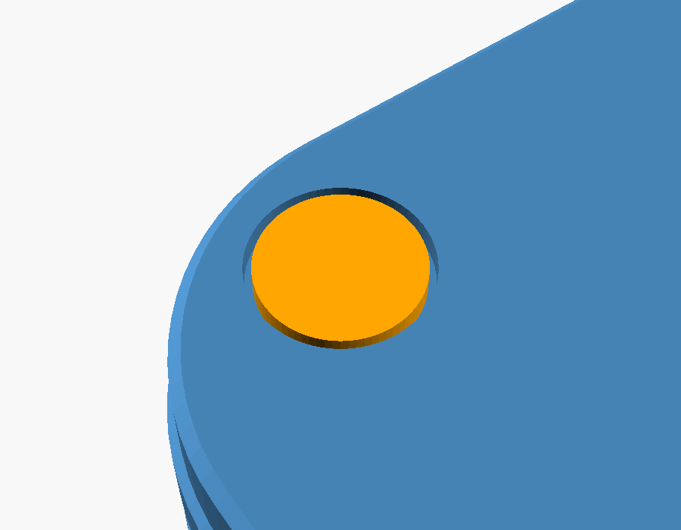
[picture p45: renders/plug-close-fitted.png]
|  |  |

Section: the plug's cap in its recess, its ribbed shank in the bore

## Desk stand

The two-part version ([README](README.md#or-the-desk-stand)). Parts are the same as above, except:

| Part | Notes |
|---|---|
| **Head** | `amoled18_stand_head.stl`: one, whatever the battery. Its collar shows between the box and the display, so print it in a colour of its own if you want to tell units apart |
| **Box** | `amoled18_stand_box_<battery>.stl`, for your battery. Its rim has a 45° ramp the head's collar nests on. Print the head and the box from the same version of the files: a head from before October 2026 has tighter corners and won't go into a current box |
| **4 × M2 × 5 socket head screws** | Display to head. A 1.5 mm hex key reaches down the 4 mm holes. (The head without a collar, `amoled18_stand_head_no_collar.stl`, takes M2 × 4) |
| **6 × M2 × 8 countersunk (flat head) screws** | Head to box: two on each side, one in the top, one in the bottom. DIN 965 (Phillips) or DIN 7991 (hex). Their heads sit flush in the box's countersunk holes, and they cut their own thread in the head. Shorter than 8 mm won't bite enough |
| No plugs | The head's back is hidden inside the box |

### Print

Both with the settings in step 2. The head goes back face down, like the plate; the box stands
on its bottom as the file loads, sloped top up. Neither needs supports: the underside of the
head's collar slopes at 45°, so nothing overhangs.

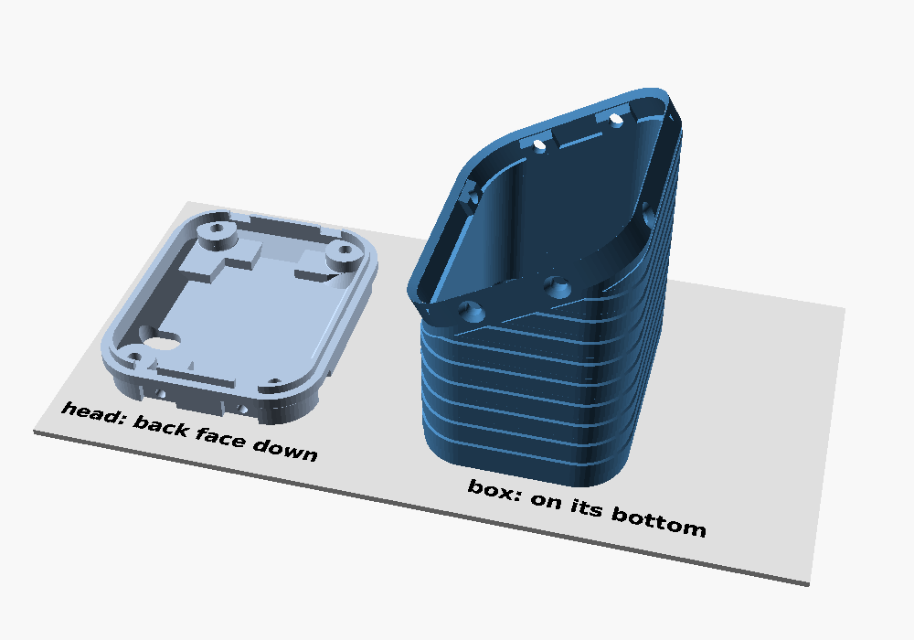
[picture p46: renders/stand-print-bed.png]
The head back face down, the box on its bottom


The band round the box's angled end — the wall round the head, which the front shell sits on — is
only 1.1 mm thick (2.25 mm at the six screw pads). Check the slicer preview shows it solid (two or
three lines), as for the plate's rim.

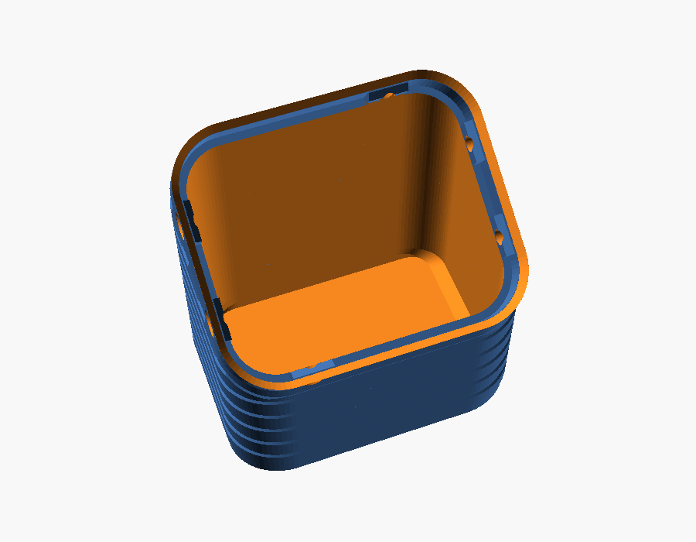
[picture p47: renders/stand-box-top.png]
The box from above: the thin wall the front shell sits on, the six screw pads on its inside, and the ledge the head rests on


### Assemble

The head screws to the display before it goes into the box, and the battery's plug has to reach
the board through the head, so it goes in this order:

The head from inside: the slot the plug comes up through, just in front of the board's BAT socket

1. **Clear the towers** in the head, as in step 3.
2. **Battery into the box**: check its polarity (step 5). With the box standing as it printed,
   tape the battery to the floor, pushed against the long flat wall — the side the stand will
   lie on. To find the wire end, stand on the long flat wall's side and look down into the box:
   the wires go to your right, the same side as the head's slot.
3. **Plug through the head**: with the head off, feed the battery's plug up through the slot in
   the head's floor, from the back, then push it into the board's `BAT` socket. The socket's
   mouth faces the slot, so the plug goes straight in.
4. **Head onto the display**: seat it on the front shell. It only goes one way that works: the
   slot sits beside the socket, near the screen's bottom edge, right of centre, and the USB-C
   and buttons are on the top edge. Screw it on with the four M2 × 5 (step 6), only until
   they're snug: the tower tops sit 0.5 mm below the shell's edge, so the screws close that gap. Keep the box
   beside it while you work; the wire is short.
5. Lay the foam on the battery, tuck the spare wire into the box, and **lower the head into the
   box's sloped end**, USB-C side to the box's short wall — away from the long flat wall. Its
   six notches drop over the pads inside, and it sinks in until its back rests on the ledge and
   its collar sits on the box's rim.
6. **Lock it**: drive an M2 × 8 countersunk screw through each of the six holes round the box's
   rim into the head, until its head sits flush. Snug, not tight — it's cutting its own thread
   in plastic.
7. **Lay it down** on its long flat side, screen facing you: the USB-C and buttons are now along
   the top.

How the head sits in the box, cut through a side wall at a lock screw

The desk stand as it sits, cut open: the head on the box's ledge, the battery (green) lying on the long flat side

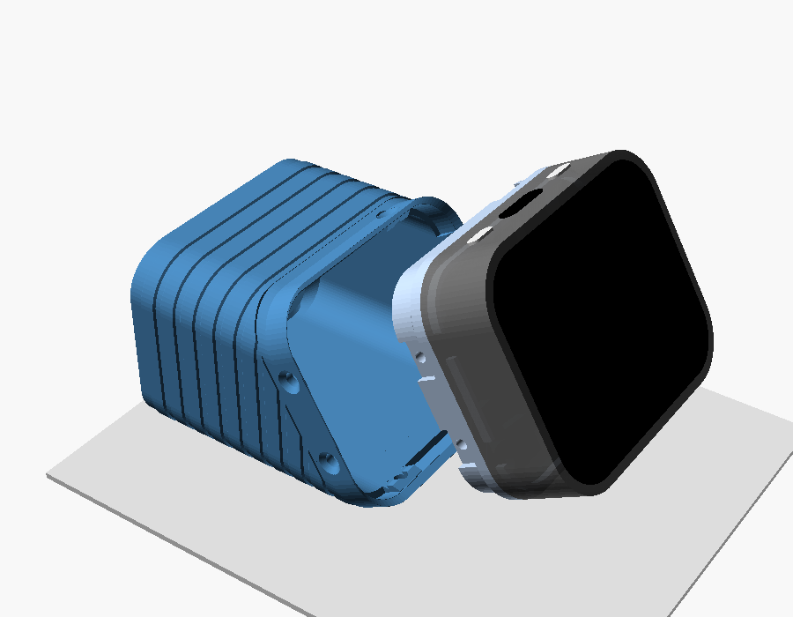
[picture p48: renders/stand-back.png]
Apart: the display on its head, and the box it sinks into; the USB-C and buttons are on the top edge


To charge, plug into the USB-C on the top edge; nothing needs taking apart. To take it apart,
undo the six rim screws and lift the head out.

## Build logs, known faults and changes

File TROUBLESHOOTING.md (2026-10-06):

# Troubleshooting

> **Status:** Living · **Last verified:** 2026-10-06

Something came out wrong? Find it below. Each fix names the field to change in OpenSCAD —
[MODEL_ADJUSTMENT.md](MODEL_ADJUSTMENT.md) shows how to open the model, change a field and export.
Back to the [README](README.md).

**First, always:** open the `.scad`, pick your version from the Customizer's drop-down, press
**F5** and read the console. It lists every clearance the model worked out.

## Fitting the case

The rim and the front shell

| Problem | Likely cause | Fix |
|---|---|---|
| **Rim won't go into the front shell** | Rim a little big | Raise `lip_slop` by 0.1; or measure the stock rim and lower `lip_outer_x` / `lip_outer_y` |
| **Plate wobbles or rattles on the shell** | Rim a little small | Lower `lip_slop` by 0.1 (not below 0); or raise `lip_outer_x` / `lip_outer_y` |
| **Rim sits proud, won't go all the way in** | Rim too tall | Measure the stock rim and lower `lip_h` |
| **Holes don't line up with the brass standoffs** | Screw spacing | Measure hole to hole on the stock cover and set `screw_dx` / `screw_dy` to half of each ([outline figure](renders/fig-outline.png)) |

## Screws and towers

Top of a screw tower

| Problem | Likely cause | Fix |
|---|---|---|
| **Screw won't go down the tower**, or the hex key jams | Thin top layer not cleared, or the bore printed small | Push the layer through with a 2 mm drill; if the bore itself is tight, raise `hole_slop` by 0.1 |
| **Gap at the seam**, the rim won't go all the way into the shell, or the board feels pushed forward | Towers too tall: they hit the standoffs before the rim is in | Measure the gap and raise `tower_drop` by that much (2, the default, matches standoffs that end level with the shell's edge) |
| **Board rattles, or tightening pulls it backwards** | Towers too short to reach the standoffs | Lower `tower_drop` by the gap (it can go negative) |
| **Screw spins without gripping** | Screw too short | Next length up, staying under the [limit](DESIGN.md#screws) |
| **Screw feels like it hits something, or the display looks pressed** | Screw too long | **Stop.** Use a shorter screw — the tip is reaching the display |

## Battery

Where the cell sits

| Problem | Likely cause | Fix |
|---|---|---|
| **Console says `CELL DOES NOT FIT`** | Cell too big for this orientation | Try another `battery_orientation` (edge, flat, end), or a smaller cell |
| **Battery won't go in** | Cell bigger than its listing, or wires in the way | Measure the cell including its folded circuit board, enter it, re-export; raise `lead_end` for wire room |
| **Battery slides around** | Too much space | More foam — that's what it's for |
| **Foam or battery pressing on the board** | Not enough headroom | Thinner foam, or raise `lead_space` by 1–2 mm |
| **Nothing happens when connected** | Plug reversed | Unplug at once and check polarity against the board's `+`/`−` marks ([PRINTING.md](PRINTING.md#5-fit-the-battery)) |

## Hole plugs

A fitted plug in section

| Problem | Likely cause | Fix |
|---|---|---|
| **Plugs fall out** | Your printer makes holes big | Raise `plug_interference` by 0.05, set `part` = plugs, export again |
| **Plugs won't go in** | Your printer makes holes small | Lower `plug_interference` by 0.05 |
| **Plug won't sit flush** | Stringing in the recess | Clean the recess with a knife; or lower `plug_cap_t` a touch |

## Print quality

Bottom of the wall on the bed

| Problem | Likely cause | Fix |
|---|---|---|
| **Back edge flares out at the bottom** (elephant's foot) | First layer squashed | Raise `edge_chamfer` to 0.6, or lower the bed temperature |
| **Corners lift off the bed** | Warping | Add a brim; clean the bed; PETG on a textured or glue-sticked bed |
| **Rim prints thin or broken** | Slicer drew one line instead of two | Enable thin-wall detection ("Arachne") in the slicer; or raise `lip_wall` to 1.0 (costs 0.4 mm of battery room) |
| **Rough spot at the top of each screw hole** | The bridged layer sagged a little | Normal; it's cleared anyway in assembly |
| **Ribs too strong or too subtle** | Taste | `grip_depth` 0.2–0.5, or 0 for smooth ([comparison](MODEL_ADJUSTMENT.md#grip-ribs)) |
| **Unit too thick** | Battery choice | Use the flat 802525 version (24.7 mm) |

## Desk stand

Where the head sits in the box

| Problem | Likely cause | Fix |
|---|---|---|
| **Console says `CELL DOES NOT FIT THE BOX`** | Cell too wide for the box, or its corners reach the rounded corners | Another `battery_orientation`; or lower `stand_ledge` a little |
| **…and suggests a lower `stand_angle`** | A wide cell doesn't fit at a big lean | Lower `stand_angle` |
| **Console says `RIM IS LARGER THAN THE HEAD`** | `pocket_wall` + `pocket_clear` too big | Lower one of them |
| **Head won't drop into the box** | Opening printed small, or a pad catching its notch | Check the six notches line up with the pads (the head goes in either way round); raise `pocket_clear` by 0.05 and print again |
| **Head rattles in the box** | Opening printed big | The head presets already use the tightest `pocket_clear` (0.05); check the box's flow and wall settings. The rim screws hold it anyway |
| **Front shell stands proud of the box** | Head not right down on the ledge | Check nothing (foam, wire) is under the head's back; thinner foam |
| **…with the head right down, a strip of it showing under the shell** | The board's standoffs reach past the shell's edge and land on the tower tops first | Measure the gap and raise `tower_drop` by that much in the head preset; the lock blocks drop with the towers |
| **…and the head's rim touches the inside of the shell first** | Rim taller than the shell's inside step | Lower `lip_h` and `stock_clear` by the same amount, and `tower_drop` with them |
| **Front shell won't press onto the head's rim** | Rim a little big for this shell | Raise `lip_slop` to 0.1 in the head preset |
| **Display screws don't bite, or bottom out** | Wrong length for the head | M2 × 5 for the collar head, M2 × 4 for the head without a collar; the console's `SCREWS` line gives it |
| **Underside of the collar droops** | A head from before the collar's underside was sloped | Reprint the head and box from the current files: the collar's underside is now 45° |
| **Speaker or mic sounds muffled** | The rim covers the U-shaped notch in the front shell's edge | Use current files (the rim has slots there); if your shell's notch is elsewhere, move `mic_slot_x` to its centre |
| **Front shell overhangs the box, or the box sticks out** | The case outline differs from the drawing | Measure the stock cover and correct `plate_x`, `plate_y`, `plate_r` |
| **Head sits proud, rocking on the battery** | Foam too thick, or the cell is bigger than entered | Thinner foam; measure the cell and enter it, which makes the box longer |
| **Plug won't go through the slot** | A bigger plug than the usual MX1.25 | Open the slot with a file; the plug only has to pass once |
| **Plug won't reach the `BAT` socket** | Short wires | Extend the wires (the cell has little room to move over) |
| **Lock screw won't bite** | Its hole in the head is too big, or the screw is shorter than 8 mm | Use M2 × 8; a drop of glue in the hole |
| **Lock screw won't go in** | Its hole in the head is too small | Open it with a 1.5 mm drill |
| **Lock screw head stands proud** | Countersink printed small, or a pan-head screw | Use countersunk (flat head) screws; clean the seat with a countersink bit or a 5 mm drill turned by hand |
| **The band round the box's angled end is broken or missing at its corners** | A box from before the corners were widened: the band was only 0.3 mm thick there | Reprint the box from the current files: the band is now 1.1 mm all the way round |
| **The band round the box's angled end cracks at a lock screw** | Screw overtightened | Snug only; print the box with more walls |
| **USB-C and buttons end up at the bottom** | Head in the box the wrong way round | The USB-C side goes to the box's short wall, away from the long flat side it lies on |
| **Screen leans back too much or too little** | Taste | `stand_angle`, 10–45° |

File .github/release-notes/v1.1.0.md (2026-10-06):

## v1.1.0

Fixes to the desk stand from test prints. **Reprint both the head and the box:** a head from
v1.0.0 won't go into a v1.1.0 box.

- **The box's top band is 1.1 mm all the way round.** At the corners it used to pinch to 0.3 mm,
  too thin to print, and came out broken. The head's corners are rounder to match.
- **The collar's underside slopes at 45°**, and the box's band has a matching ramp it sits on,
  so the collar no longer sags when printed.
- **The speaker/mic opening is clear.** The rim had blocked the U-shaped notch in the front
  shell's edge; it now has slots there. The back plates get the same slots.
- The box meshes are clean everywhere (one had a small non-manifold edge).

| Part | File |
|---|---|
| Desk stand head, with collar | `amoled18_stand_head.stl` |
| Desk stand head, without collar | `amoled18_stand_head_no_collar.stl` (needs a box exported with `collar_h` 0) |
| Boxes | `amoled18_stand_box_103035_edge.stl`, `amoled18_stand_box_802525_flat.stl`, `amoled18_stand_box_104050_end.stl` |
| Back plates | `back_plate_103035_1000mAh_edge.stl`, `back_plate_802525_400mAh_flat.stl`, `back_plate_104050_2400mAh_end.stl` |
| Hole plugs | `amoled18_hole_plugs.stl` |

Screws: 4 × M2 × 5 socket head (display to the collar head; M2 × 4 for the other head and for the
back plates), 6 × M2 × 8 countersunk (head to box).

How to print and put it together: [PRINTING.md](https://github.com/jeffmhopkins/esp32-s3-touch-amoled-1.8-case/blob/v1.1.0/PRINTING.md)

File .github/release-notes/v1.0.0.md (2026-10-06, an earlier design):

## v1.0.0

3D-printable cases for the Waveshare ESP32-S3-Touch-AMOLED-1.8: a deep back plate that holds a
real battery, and a desk stand.

### Back plate

One file per battery. Print one, plus the optional hole plugs.

| Battery | File |
|---|---|
| 103035, 1000 mAh, on its edge (recommended) | `back_plate_103035_1000mAh_edge.stl` |
| 802525, 400 mAh, flat | `back_plate_802525_400mAh_flat.stl` |
| 104050, 2400 mAh, on its end (tight, measure first) | `back_plate_104050_2400mAh_end.stl` |
| Hole plugs, optional (not for babies) | `amoled18_hole_plugs.stl` |

Screws: 4 × M2 × 4 socket head.

### Desk stand

One head, plus the box for your battery.

| Part | File |
|---|---|
| Head, with a 3 mm collar | `amoled18_stand_head.stl` |
| Head, without the collar (alternative) | `amoled18_stand_head_no_collar.stl` |
| Box for the 103035 (recommended) | `amoled18_stand_box_103035_edge.stl` |
| Box for the 802525 | `amoled18_stand_box_802525_flat.stl` |
| Box for the 104050 (tight, measure first) | `amoled18_stand_box_104050_end.stl` |

The collar shows as a band between the box and the display, so print the head in a different
colour for each unit to tell them apart.

Screws: 4 × M2 × 5 socket head to hold the display on the head (M2 × 4 for the head without the
collar), and 6 × M2 × 8 countersunk to hold the head in the box.

How to print and put it together: [PRINTING.md](https://github.com/jeffmhopkins/esp32-s3-touch-amoled-1.8-case/blob/v1.0.0/PRINTING.md)

Licensed CC BY-SA 4.0.

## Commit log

2026-09-22 feat(hardware): printable deep back plate for the AMOLED-1.8 panels (#1500)
    * feat(hardware): add parametric deep back plate for the AMOLED-1.8 panel
    A printable replacement for the stock back cover of the Waveshare
    ESP32-S3-Touch-AMOLED-1.8, deep enough to hold a real LiPo. OpenSCAD
    source, a sample STL, a render, and photos of the actual unit.
    Claude-Session: https://claude.ai/code/session_01XQyqm226ed74HHMbdFsJd9
    * docs(hardware): beginner walkthrough for editing and printing the back plate
    Claude-Session: https://claude.ai/code/session_01XQyqm226ed74HHMbdFsJd9
    * fix(hardwa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
    [amoled18_back_plate.scad, back_plate_802525_400mAh.stl]
2026-09-22 feat(hardware): back plate v2 (screw towers, 1000 mAh default, plugs, grip ribs) (#1501)
    * feat(hardware): open straight-walled cavity; cells can stand on edge
    The back plate becomes a tall box: the whole inside is open except the
    screw posts, with straight walls up to the rim so nothing overhangs, and
    gaps are padded with foam. A new battery_orientation setting stands a
    cell on its long edge, which lets a 1000 mAh 852540 fit between the
    posts; the unit comes out about 37.6 x 45.2 x 39 mm. The rim wall drops
    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
    [amoled18_back_plate.scad, amoled18_hole_plugs.stl, back_plate_103035_1000mAh_edge.stl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]
2026-09-23 feat(hardware): 45° flare at each screw-tower base; plug renders (#1502)
    The screw towers met the 1.6 mm floor at a sharp 90 degrees on the
    cavity side. Each now flares out 2 mm at 45 degrees, shrinking near the
    cell by the same rule as the wall chamfer. README gains renders of the
    back with and without plugs, close-ups and a section of a fitted plug.
    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
    [amoled18_back_plate.scad, back_plate_103035_1000mAh_edge.stl, back_plate_104050_2400mAh_end.stl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]
2026-09-23 docs(hardware): back plate README built for the person printing it (#1503)
    Quick start (versions, parts, print settings, assembly), a 'what you
    want -> which setting' table, and a 'problem after printing -> fix'
    table up front; the design detail moves below. The model's hole
    allowance moves to the Screws group, and tower_drop can go negative for
    stock posts that stand above the rim.
    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
    [amoled18_back_plate.scad]
2026-09-23 docs(hardware): split the back plate guide into focused docs with labelled renders (#1505)
    README becomes a short landing page (what it is, the three versions,
    links). PRINTING.md, MODEL_ADJUSTMENT.md, TROUBLESHOOTING.md and
    DESIGN.md hold the detail, illustrated throughout: labelled sections of
    the rim, floor and screw towers, a dimensioned outline, the battery
    layout, each version cut open, grip depths, the print bed and the plugs.
    All images move to renders/, generated from the model by
    renders/make_renders.sh with dimension lines and labels drawn in
    OpenSCAD (renders/src/annot.scad). A hidden show_part switch lets
    figure files include the model without drawing it.
    Claude-Session: https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
    [amoled18_back_plate.scad, annot.scad, fig_back_plugs.scad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]
2026-09-23 feat(hardware): flat full-width tower tops; two-layer bridge skin (#1506)
    The towers now meet the board's nuts with a flat, full-width top
    instead of a 0.5 mm stepped pad (nut_pad_h defaults to 0, kept as an
    option). The skin closing each bore doubles to 0.4 mm, and the guides
    now call for a 2 mm drill to clear it. STLs, renders and docs updated.
    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
    [amoled18_back_plate.scad, back_plate_103035_1000mAh_edge.stl, back_plate_104050_2400mAh_end.stl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]
2026-09-23 feat(hardware): tilted stand variation for the AMOLED back plate (#1507)
    tilt_angle cuts the plate's bottom-back corner flat at that angle, so the
    unit stands on a table leaning back, resting on the sloped face and the
    front shell's bottom edge. The cavity is clipped behind a tilt_wall-thick
    sloped wall, the cell moves up the cavity when it needs to, and the fit
    check includes the sloped wall. Only thin flat-battery plates keep room
    for a cell; the new preset and STL are the 802525 flat at 20 degrees.
    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
    [amoled18_back_plate.scad, back_plate_802525_400mAh_tilt20.stl, fig_tilt_stand.scad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]
2026-09-23 feat(hardware): two-part desk stand for the AMOLED-1.8 unit (#1509)
    Replaces the tilted-plate variation with a desk stand: a stock-depth head
    that screws to the display, and a plain battery box whose top is cut at
    30 degrees to take the head in a pocket, locked by one screw at each end.
    Landscape, USB-C and buttons on the top edge. Boxes for the 103035,
    802525 and 104050 cells, with renders and docs.
    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
    [amoled18_back_plate.scad, amoled18_stand_box_103035_edge.stl, amoled18_stand_box_104050_end.stl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]
2026-09-23 feat(hardware): flush two-part desk stand, lying on its side with USB-C on top (#1510)
    * feat(hardware): make the desk stand one piece, flush with the case
    The box's tilted top is now the back plate itself: the rim enters the
    front shell, the outside is flush with the case outline, and four towers
    hang from the seam, braced into the end walls. The screws are driven with
    a long hex key through holes in the floor and back wall lined up with
    each screw. Cells must stay under 31 mm left to right to clear the screw
    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
    [amoled18_back_plate.scad, amoled18_stand_box_103035_edge.stl, amoled18_stand_box_104050_end.stl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]
2026-09-23 feat(hardware): desk stand README pictures, four lock screws, staleness scrub (#1512)
    * docs(hardware): show each desk stand battery version in the README
    Adds a picture row to the desk stand table, like the back plate's, using
    the cut-open renders of the three boxes.
    * feat(hardware): four lock screws on the desk stand, two each side
    The head is held in the box by two M2x6 on each side, lock_spread
    (14 mm) apart, instead of one in the middle; each gets its own lock
    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
    [amoled18_back_plate.scad, amoled18_stand_box_103035_edge.stl, amoled18_stand_box_104050_end.stl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]
2026-09-24 feat(hardware): flush countersunk lock screws with thicker pads, six round the desk stand's rim (#1516)
    * feat(hardware): flush countersunk lock screws, six round the desk stand's rim
    The lock screws were pan heads standing ~1.3 mm proud of the box. They
    are now M2 x 6 countersunk (flat head) screws in 0.8 mm 90-degree seats
    in the 1.1 mm band, so they sit flush; the holes move to 1.45 mm above
    the ledge to keep the seats under the seam. One more screw goes in the
    top and bottom sides (lock_top_bottom), diagonally opposite so they
    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
    [amoled18_back_plate.scad, amoled18_stand_box_103035_edge.stl, amoled18_stand_box_104050_end.stl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]
2026-10-04 fix(hardware): stop the screw towers at the seam, where the standoffs end (#1562)
    A first print showed the board's brass standoffs end exactly level with
    the front shell's edge. With tower_drop 0 the towers stood level with the
    rim top, so they hit the standoffs while the rim was still outside the
    shell, leaving a 2 mm gap at the seam. tower_drop now defaults to 2 (the
    rim's height): tower tops sit at the seam and the rim goes fully in.
    On the desk stand's thin head the seat thins to 1.4 mm so a socket head
    still fits below its back face.
    Head and plates re-exported (boxes and plugs unchanged); all single
    watertight bodies, no feature under 0.7 mm, head still fits the box with
    all six lock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
    [amoled18_back_plate.scad, amoled18_stand_head.stl, back_plate_103035_1000mAh_edge.stl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]
2026-10-04 feat(hardware): photoreal hero shots for the AMOLED back plate and desk stand (#1563)
    * feat(hardware): photoreal Blender pipeline for the README hero shots
    Adds renders/photoreal/: OpenSCAD part exports, Waveshare's STEP as glTF,
    the firmware's own pet on the glass, rendered in Cycles via bpy. The README's
    top pictures move to the two photoreal shots (images follow in the next commit).
    * feat(hardware): orange and black versions of each photoreal shot
    Claude-Session: https://claude.ai/code/session_01XQyqm2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
    [parts.scad]
2026-10-06 Add snug "Allan fitment" desk-stand head preset and STL
    A printed head was loose in its box, and the rim held the front shell
    above the box face. The new preset tightens the head-to-box and
    rim-to-shell gaps to 0.05 mm and lowers the rim and towers to 1.5 mm.
    The box is unchanged.
    stock_clear is also lowered to 3.4. In desk mode the body height is
    stock_clear - lip_h, so lowering lip_h alone would make the body 0.5 mm
    taller and push the head 0.5 mm further out of the existing box.
    Claude-Session: https://claude.ai/code/session_0115imstn3UbypdBBi1VCPhB
    [amoled18_stand_head_allan_fitment.stl]
2026-10-06 Add ALLAN_FITMENT.md describing the snug desk-stand head
    Explains the original fit problem (with photos), links the new head
    STL and its preset, lists each parameter change and why, and says what
    to adjust if the print still doesn't fit. README links to it.
    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
2026-10-06 Restructure ALLAN_FITMENT.md as problem, cause, fix, result
    The doc now goes: the problem (photos), why it happened (side-wall cut
    of the stock head), the fix (parameter table), and why it's fixed
    (before/after cut).
    New figures:
    - a cut with only the rim lowered, showing why stock_clear has to drop
    with lip_h (otherwise the body grows 0.5 mm and the head stands out
    of the box)
    - close-ups of the head-to-box and rim-to-shell gaps, drawn to scale,
    before and after
    fig_allan_fitment.scad measures the shell's height from the stock box's
    band, so the cut with only the rim lowered comes out right. It also
    gets a close-up mode. make_renders.sh regenerates all of these.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
    [fig_allan_fitment.scad]
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2026-10-06 Add a collar ring between the desk-stand box and the front shell
    New collar_h parameter (0 = none) and part = collar. The collar is a
    plain ring: the case outline outside, the box's opening inside. It sits
    on the box's band, and the front shell sits on it. The head grows by
    collar_h and passes up through it. The box is built to the new pocket_h
    (the head's height without the collar), so it doesn't change at any
    collar height.
    With a collar, the lock blocks stop at the top of the box's band, so
    they sit collar_h further below the board. The towers grow with the
    head, which brings their screw seat back to the full 2 mm.
    The Allan fitment head now uses a 3 mm collar, with a matching
    "Desk sta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
    [amoled18_back_plate.scad, amoled18_stand_collar_allan_fitment.stl, amoled18_stand_head_allan_fitment.stl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]
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2026-10-06 Build the collar into the head instead of a separate ring
    collar_h now adds the collar to the head itself: above the box's band
    the head widens to the case outline, so the collar sits on the band and
    the front shell sits on it, flush with both. Print the head in any
    colour to tell units apart. The separate collar part, its preset and its
    STL are gone.
    With a collar, the head's lock-pad notches stop 0.05 mm short of the
    collar's underside so the two don't share an edge (that edge made the
    mesh non-manifold). The box's pads are still 0.15 mm below the notches.
    Without a collar nothing changes.
    The collar head is watertight and touches each of the three box STLs
    only on the ledge and the band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
    [amoled18_back_plate.scad, amoled18_stand_collar_allan_fitment.stl, amoled18_stand_head_allan_fitment_collar.stl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]
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2026-10-06 Make the new heads the main desk-stand heads
    The collar head is now amoled18_stand_head.stl, and the preset
    "Desk stand: head (fits every box)" holds its values. The same head
    without the collar is amoled18_stand_head_no_collar.stl, with the
    preset "Desk stand: head, no collar". The separate allan_fitment STLs
    and presets are gone. Both new files are geometrically identical to the
    allan_fitment STLs they replace (checked by mesh difference). The old
    head is in history, and the model's defaults (which the boxes are built
    from) still build it.
    README, PRINTING, DESIGN, ALLAN_FITMENT and the render scripts now use
    the new names.
    Claude-S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
    [amoled18_stand_head.stl, amoled18_stand_head_allan_fitment_collar.stl, amoled18_stand_head_no_collar.stl]
2026-10-06 Remove ALLAN_FITMENT.md and its figures
    The new heads are now the main desk-stand heads and the README,
    PRINTING and DESIGN describe them, so the separate write-up isn't
    needed. Removed: ALLAN_FITMENT.md, its renders (renders/allan-*.png),
    photos (photos/allan-*.jpg) and figure sources (fig_allan_*.scad,
    allan_box_slice.stl), and their section of make_renders.sh. README and
    DESIGN no longer link to it; DESIGN's "The collar head" section still
    lists every change. No broken links remain in the docs.
    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
    [allan_box_slice.stl, fig_allan_box_slice.scad, fig_allan_fitment.scad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]
2026-10-06 Bring the guides up to date with the new desk-stand head
    MODEL_ADJUSTMENT: the desk-stand presets by name, a new "The head
    presets" table of every field they change from the defaults (and a
    warning not to copy the head's lock_pad / stand_ledge into a box
    preset), the head preset's values in the pocket_clear and lock_pad
    rows, the console's new lines, and the collar being the only part of
    the head that shows.
    TROUBLESHOOTING: new desk-stand rows for a shell held up by the towers
    (raise tower_drop) or by the rim (lower lip_h and stock_clear), a shell
    that won't press onto the rim (lip_slop), display screw length (M2 x 5
    with the collar), and a drooping collar underside. The "head rattles"
    row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
2026-10-06 Slope the collar's underside at 45 degrees and clear the speaker/mic notch
    Collar: the collar's underside sagged where it overhung the head by
    about 1.2 mm. With collar_chamfer (on by default) it now rises at 45
    degrees from the head's side, and the box's band gets a matching 45
    degree ramp the collar nests on. The ramp is defined from the box's
    opening, which pocket_clear doesn't change, so the head's chamfer
    clears it by pocket_clear + 0.05 (0.1 mm). The box presets now set
    collar_h = 3 to get the ramp. The head still touches each box only on
    the ledge. Boxes made with collar_h = 0 keep the flat band, for the
    no-collar head.
    Speaker/mic: the rim sat right behind the U-shaped notch in the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
    [amoled18_back_plate.scad, amoled18_stand_box_103035_edge.stl, amoled18_stand_box_104050_end.stl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]
2026-10-06 Widen the box's band at its corners (0.3 mm -> 0.9 mm)
    The head's corners (R5.55-5.65) were much tighter than the case's
    (R8.7), so the box's band, between the two outlines, pinched to 0.31 mm
    along each corner's diagonal. That's too thin to print, and it is
    where printed boxes came out broken at the corners.
    New pocket_corner_min (0.9): the box's opening corner radius is the
    smallest that keeps the band at least that thick along the diagonal,
    and the head's corner is that minus pocket_clear. That still leaves
    0.88 mm of wall outside each screw bore in the shipped head (was
    1.15). The console reports both numbers.
    The rounder corners leave the cell a little less room near the corners,
    so t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
    [amoled18_back_plate.scad, amoled18_stand_box_103035_edge.stl, amoled18_stand_box_104050_end.stl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]
2026-10-06 Make the box's band the same 1.1 mm all the way round
    The box's opening is now the case outline offset in by pocket_wall
    (corner radius plate_r - pocket_wall), so the band is a constant 1.1 mm,
    corners included, instead of pinching at the corners. The head follows,
    pocket_clear inside the opening. This replaces pocket_corner_min.
    Rounder head corners leave less wall outside each screw bore, so the
    head presets set head_clear 0.4 (was 0.6), which keeps 0.83 mm there.
    The stock plates don't change.
    The box's lock pads now stop 0.01 mm short of the ledge's edge. With
    the new corner they shared an edge with it, which made the 802525 and
    104050 boxes non-manifold.
    All heads and boxes re-export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
    [amoled18_back_plate.scad, amoled18_stand_box_103035_edge.stl, amoled18_stand_box_104050_end.stl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]
2026-10-06 Bring the guides up to date; add v1.1.0 release notes
    README: the collar's underside is sloped and prints without supports.
    PRINTING: print the head and box from the same version of the files
    (an older head's tighter corners won't go into a current box).
    MODEL_ADJUSTMENT: collar_h on a box adds the 45 degree ramp. DESIGN: the
    desk-stand heads' tower bore is 4.4 mm. Release notes for v1.1.0 list
    the stand fixes and say to reprint head and box together.
    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
